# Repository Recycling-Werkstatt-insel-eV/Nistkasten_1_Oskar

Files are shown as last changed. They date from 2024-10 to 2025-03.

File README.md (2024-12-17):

# Vogelnistkasten aus Recycling-Kunststoff und Holz - für Bauworkshops

Dieser Vogelnistkasten wurde so konzipiert, dass einige Teile aus Recycling-Kunststoff (Plastikplatten aus der "Precious-Plastic"-Plattenpresse) und Wände sowie der Boden aus Holzplatten bestehen. Die Holzteile lassen sich mit einem geeigneten Lasercutter ausschneiden oder auch mit einer CNC-Fräse aus Holzbrettern fräsen.

Durch seinen einfachen Aufbau ist dieser Nistkasten sehr gut für Bauworkshops geeignet, sowohl für Grundschulkinder als auch für ältere Jugendliche oder Erwachsene.

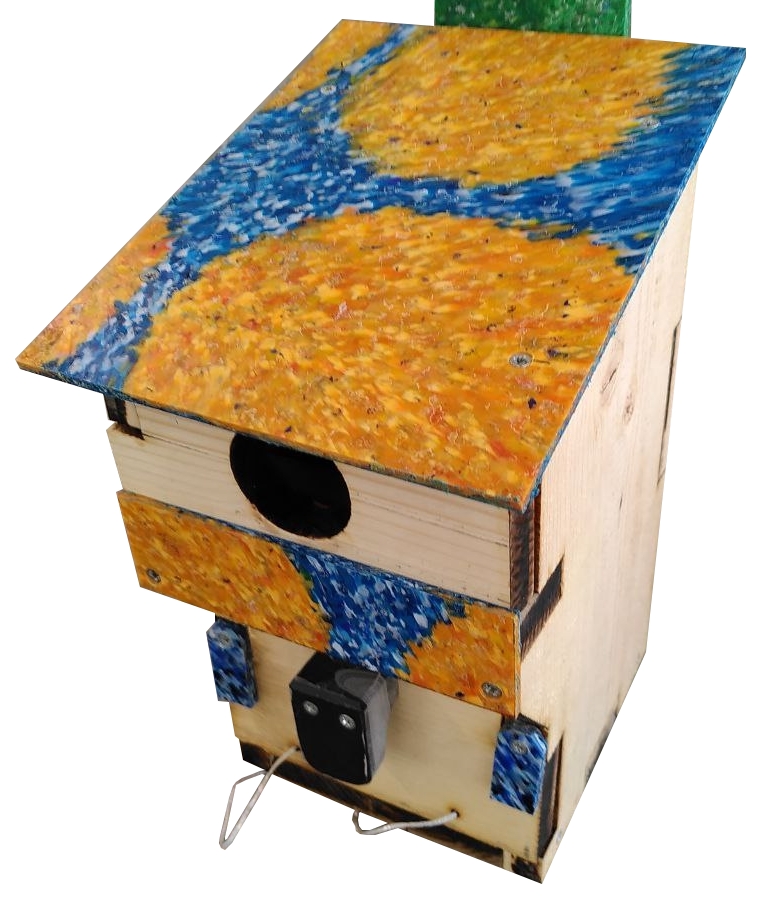
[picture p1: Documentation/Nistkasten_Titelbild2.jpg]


Im Rahmen dieses Projekts wurden noch einige andere Nistkästen entwickelt: [Zur Übersicht](https://github.com/orcular-orga/vogelhaus_uebersicht)

## Bauanleitung

Für einen Nachbau wird empfohlen, die folgenden Kapitel in der vorgesehenen Reihenfolge zu lesen und die Schritte entsprechend abzuarbeiten:

1. 💡 [Hintergrundinfos](Documentation/Hintergrundinfos/Hintergrundinfos.md)
2. 🛒 [Einkaufsliste](Documentation/Einkaufsliste/Einkaufsliste.md)
3. 🪵 [Fertigung der Holzteile (Lasercutting oder CNC-Fräsen)](Documentation/Fertigung_der_Holzteile/Fertigung_der_Holzteile.md)
4. ♻️ [Fertigung der Kunststoffteile](Documentation/Fertigung_der_Kunststoffteile/Fertigung_der_Kunststoffteile.md)
5. 🛠️ [Zusammenbau](Documentation/Documentation.md)
6. 🐣 [Aufhängung der Kästen und Pflege](Documentation/Aufhaengung_Pflege/Aufhaengung_Pflege.md)

## CAD + Open Source

Dieser Nistkasten wurde in der Open-Source-Software FreeCAD entwickelt. Die Datei kann im Ordner CAD heruntergeladen werden:

- [Download der CAD-Datei (FreeCAD)](CAD)

Die Software FreeCAD ist kostenlos und kann auf https://www.freecad.org/ heruntergeladen werden:

- [Download der Software FreeCAD](https://www.freecad.org/)

Alle Bauteile und Objekte in der CAD-Datei des Nistkastens können mit FreeCAD verändert werden, sodass es möglich ist, weitere Varianten zu entwickeln und ggf. öffentlich zu teilen, so wie dieses Projekt - ganz im Sinne von Open Source Hardware.

## Lizenz

Das Design, die CAD-Dateien, die Materiallisten und alle dazugehörigen Dateien dieses Vogelnistkastens sind unter folgender Lizenz veröffentlicht:

- [CERN Open Hardware Licence Version 2 Weakly Reciprocal - CERN-OHL-W](https://cern-ohl.web.cern.ch/)

Die Dokumentation, Bauanleitung, Abbildungen und Texte in diesem Verzeichnis sind unter folgender Lizenz veröffentlicht:

- [Creative-Commons-Attribution-ShareAlike 4.0 International - CC BY-SA 4.0](http://creativecommons.org/licenses/by-sa/4.0/)

**Autor:** Oskar Lidtke, https://github.com/orcular-org/

<br />Except where otherwise noted, this work is licensed under a <a rel="license" href="http://creativecommons.org/licenses/by-sa/4.0/">Creative Commons Attribution-ShareAlike 4.0 International License (CC BY-SA 4.0)</a>.

Für die empfohlene, korrekte Anwendung der Creative-Commons-Namensnennung (engl. "attribution"), siehe [hier](https://wiki.creativecommons.org/wiki/Best_practices_for_attribution) und für die Kennzeichnung der eigenen Arbeit mit Creative Commons, siehe [hier](https://wiki.creativecommons.org/wiki/Marking_your_work_with_a_CC_license).

<p align="left">
<i> <sub> Open Source Hardware logo, <a href="https://creativecommons.org/licenses/by-sa/4.0/">CC BY-SA</a> - <a href="https://www.oshwa.org/open-source-hardware-logo/">Source</a> </sub></i>
</p>



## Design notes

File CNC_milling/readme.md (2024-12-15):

Die beiden Dateien "Nistkasten_20cm_Brettbreite.svg" und "Nistkasten_25cm_Brettbreite.svg" können zum CNC-Fräsen genutzt werden (jeweils für ein Brett 800 x 200 x 18 mm bzw. 800 x 250 x 18 mm). Zum CNC-Fräsen kann je nach CNC-Fräsmaschine eine andere Software verwendet werden, z.B. Estlcam. Anleitung für das CNC-Fräsen [hier](CNC_milling_Documentation/CNC_milling.md).

Download: Eine der SVG-Datei anklicken, dann oben rechts auf die drei Punkte "..." klicken und "Download" wählen. Datei kann bei Bedarf in Vektorgrafikprogrammen geöffnet und bearbeitet werden, z.B. in Inkscape.

Die kostenlose Open-Source-Software Inkscape kann hier heruntergeladen werden: https://inkscape.org/

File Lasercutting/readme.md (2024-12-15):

Die beiden Dateien "Nistkasten_20cm_Brettbreite.svg" und "Nistkasten_25cm_Brettbreite.svg" können zum Lasercutting genutzt werden (jeweils für ein Brett 800 x 200 x 18 mm bzw. 800 x 250 x 18 mm). Zum Lasercutting kann je nach Lasercutter eine andere Software verwendet werden, z.B. Lightburn. Anleitung für das Lasercutting [hier](Lasercutting_Documentation/Lasercutting.md).

Download: Eine der SVG-Datei anklicken, dann oben rechts auf die drei Punkte "..." klicken und "Download" wählen. Datei kann bei Bedarf in Vektorgrafikprogrammen geöffnet und bearbeitet werden, z.B. in Inkscape.

Die kostenlose Open-Source-Software Inkscape kann hier heruntergeladen werden: https://inkscape.org/

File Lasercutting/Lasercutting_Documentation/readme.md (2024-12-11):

Beschreibung des Vorgehens beim Lasercutting

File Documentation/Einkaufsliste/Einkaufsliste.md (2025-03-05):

# Einkaufsliste

Die Mengenangaben in dieser Einkaufsliste beziehen sich auf **einen** Nistkasten. Falls mehrere Nistkästen gebaut werden sollen, können natürlich entsprechend größere Mengen besorgt werden.

**Zum Thema Holz:**

Der NABU empfiehlt zum Thema Holzart folgendes:

_"Verwenden Sie zum Bau von Nistkästen 1,8 Zentimeter dicke, ungehobelte Bretter aus Massivholz. Eiche, Robinie und Lärche oder Kiefer eignen sich am besten. Falls Ihnen diese Holzarten nicht zur Verfügung stehen, können Sie auch auf Fichte und Tanne zurückgreifen. Sperrholz oder Pressplatten sind nicht witterungsbeständig und daher für den Außeneinsatz ungeeignet."_

- Quelle: https://www.nabu.de/tiere-und-pflanzen/voegel/helfen/nistkaesten/index.html , Abschnitt "Das richtige Material"

Für unsere Zwecke haben wir uns für Fichtenholzbretter aus dem Baumarkt entschieden, da sie einen gutes Verhältnis aus Kosten und Eignung bieten. Zudem haben wir in unseren Tests festgestellt, dass sich Fichtenholzbretter gut mit dem Lasercutter schneiden bzw. mit der CNC-Fräse fräsen lassen. Es können aber, entsprechend der oben stehenden Empfehlungen, auch andere Holzarten verwendet werden.

**Zum Thema Recyclingkunststoff:**

Die Offene Recycling-Werkstatt vom insel e.V. Hamburg verfügt über Maschinen, mit denen sich Platten und Balken (sogenannte "Beams") aus Recyclingkunststoff herstellen lassen. Die Maschinen und Verfahren basieren auf dem "Precious Plastic"-Projekt https://www.preciousplastic.com/ (daher stammt auch der englischsprachige Begriff "Beam" - die Platten werden auf englisch "Sheets" genannt).

Die Platten und Balken können, falls die notwendigen Maschinen vorhanden sind, selbst hergestellt werden. Sie können auch bei insel e.V. https://werkstatt.insel-ev.de/ oder auf dem "Precious Plastic Bazar" https://bazar.preciousplastic.com/ bestellt werden. Als Kunststoffsorte kommen sowohl PP als auch HDPE (PE) in Frage.

Für die genauen Maße der Kunststoffteile können auch die technischen Zeichnungen in der Sektion [Fertigung der Kunststoffteile](../../Documentation/Fertigung_der_Kunststoffteile/Fertigung_der_Kunststoffteile.md) eingesehen werden.

**Zum Thema Schrauben:**

Die unten angegebenen Schraubengrößen können auch leicht abweichen, solange sie einerseits einen sicheren Halt bieten und andererseits nicht zu weit aus dem Material herausragen.

## Schrauben

- 6 x Holzschrauben vom Typ 4 x 30 
- 12 x Holzschrauben vom Typ 3,5 x 25
- 2 x Holzschrauben vom Typ 4 x 40

:bulb: Alle Schrauben möglichst mit Senkkopf (Kreuzschlitz oder Torx). Schraubengrößen können auch leicht abweichen. Abbildungen unten nur zur Orientierung, Aussehen der Schrauben kann auch abweichen.

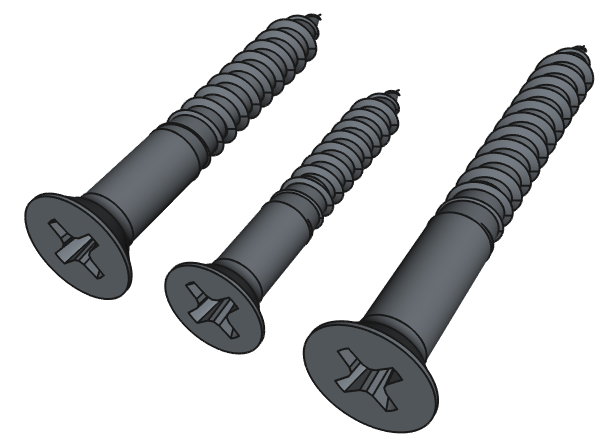
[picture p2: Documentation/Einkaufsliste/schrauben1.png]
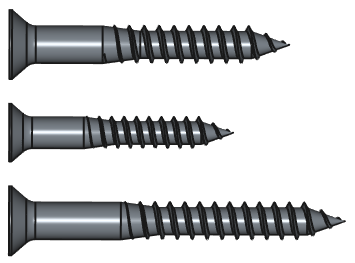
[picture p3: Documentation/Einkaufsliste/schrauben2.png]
 

## Holz

- 1x Brett 800 x 200 x 18 mm aus Fichtenholz
- 1x Brett 800 x 250 x 18 mm aus Fichtenholz

## Kunststoffplatten

- Eine oder mehrere Platten aus Recyclingkunststoff, sodass sich folgende Teile herstellen lassen:
  - 1x Frontplatte 156 x 45 mm (Stärke: 4 bis 5 mm)
  - 3x drehbarer Halter 45 x 18 mm (Stärke 4 bis 5 mm)
  - Dach 220 x 180 mm (Stärke: 5 bis 8 mm)
  - Brett Rückseite 440 x 85 mm (Stärke: 9 bis 10 mm)

Es können also beispielsweise folgende Platten besorgt werden:
- Stärke 4-5 mm, Länge/Breite mindestens 280 x 220 mm 
- Stärke 9-10 mm, Länge/Breite mindestens 440 x 85 mm

## Kunststoffbalken ("Beams")

Ein Stück 48 x 33 x 23 mm, abgeschnitten von einem Kunststoff-Balken ("Beam")

## Aluminiumnägel

Für die Befestigung der Nistkästen an Bäumen sollten pro Nistkasten zwei Alunägel verwendet werden. Mehr zum Thema im Abschnitt 6 "Aufhängung der Kästen und Pflege"

- 2x Alunägel 4,5 x 60 oder 4,5 x 80

Hier geht es [zurück zur Übersicht](../../README.md), dort weiter mit Punkt 3 "Fertigung der Holzteile (Lasercutting oder CNC-Fräsen)".

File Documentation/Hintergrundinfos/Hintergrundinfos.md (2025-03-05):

# Hintergrundinfos

Dieser Vogelnistkasten wurde im Rahmen eines Projekts bei der Offenen-Recycling-Werkstatt (von insel e.V.) in Hamburg https://werkstatt.insel-ev.de/ entwickelt. Die "Deutsche Stiftung für Engagement und Ehrenamt" hat das Projekt gefördert. Projektzeitraum war von November 2023 bis Dezember 2024.

Der Nistkasten ist für verschiedene Höhlenbrüter-Vogelarten geeignet.

Im Rahmen des Projekts sind noch andere Nistkastenmodelle entstanden. Eine Übersicht befindet sich hier: [Übersicht Nistkästen](https://github.com/Recycling-Werkstatt-insel-eV/Nistkasten_main_Uebersicht)

## Besonderheiten des Nistkastens

Ziel der Produktentwicklung war es, einen Nistkasten zu entwickeln, der
1. möglichst aus nachhaltigen Materialien hergestellt werden kann
2. einfach zusammenzubauen ist (auch von Kindern, z.B. im Rahmen von Bauworkshops)
3. mit wenig Aufwand in großer Stückzahl herstellbar ist, d.h. unter Verwendung von digitalen Fertigungsmaschinen wie Lasercutter oder CNC-Fräsen
4. gut dokumentiert ist, damit andere Menschen den Kasten nachbauen oder sogar verbessern oder neue Varianten entwickeln können
5. gut reparierbar und recyclebar ist
6. einen hohen Nutzen für die Vögel und für die Förderung von Artenvielfalt bietet

### Zu Punkt 1: Nachhaltige Materialien

Eine Besonderheit der Offene Recycling-Werkstatt von insel e.V. in Hamburg sind die Werkzeuge und Prozesse zum Recycling von Kunststoffen (Plastik) und Herstellung von neuen Produkten aus Recyclingplastik. Die Werkstatt verfügt u.a. über Granulatmühlen (Schredder) zum Zerkleinern von Kunststoffabfällen sowie über eine Plattenpresse. Das zerkleinerte Plastikgranulat kann in der Plattenpresse zu großen Platten aus Recyclingplastik gepresst werden. Diese Platten können anschließend weiterverarbeitet werden, z.B. mit Tischkreissägen oder Bohrmaschinen. 

Daher bestand ein Ziel darin, die Vogelnistkästen, zumindest teilweise, aus Recyclingkunststoff herzustellen. Während der Konzeptionsphase stellte sich heraus, dass ein Vogelnistkasten nicht vollständig aus Plastik bestehen sollte (dank der Beratung durch die teilnehmenden NABU-Mitglieder_innen). Plastikkästen heizen sich in der Sonne zu stark auf, was den Vögeln schadet, zudem ist Plastik (im Gegensatz zu Holz) nicht atmungsaktiv und es sammelt sich Feuchtigkeit im Innenraum.

Aus diesem Grund wurde ein Modell entwickelt, das teilweise aus Holz und teilweise aus Plastik besteht. Die Wände und der Boden sind aus Holz, sodass sich der Kasten nicht zu stark aufheizt, atmungsaktiv ist und zudem den Jungvögeln gute Klettermöglichkeiten an den Innenflächen bietet. Das Dach und einige weitere Verbindungsteile hingegen wurden aus Recyclingkunststoff gefertigt. Diese haben keine negativen Einflüsse auf das Innenklima. Gleichzeitig sorgt der Einsatz von Recyclingkunststoff dafür, dass wertvolles Holz zumindest teilweise eingespart werden kann. Zudem wird Kunststoffabfällen ein "zweites Leben" gegeben, oder - falls das Plastik erneut recycelt wird - sogar mehrere Leben.

### Zu Punkt 2: Einfacher Zusammenbau

Alle Teile und das gesamte Design wurden so entworfen, dass der Zusammenbau sehr einfach ist. Die Teile sind ähnlich wie ein Puzzle geformt, sodass sie sich einfach und eindeutig zusammenstecken lassen. Dadurch ist auch sichergestellt, dass die Teile richtig sitzen, nicht verrutschen und rechtwinkling zueinander angeordnet sind. Die Stellen, an denen Schrauben befestigt werden müssen, sind durch das Lasercutting bzw. CNC-Fräsen bereits vorgefertigt.

Somit ist der Kasten so konzipiert, dass er im Rahmen von Bauworkshops (ca. 1,5 Stunden) einfach zusammengebaut werden kann, auch von Grundschulkindern. Die Bauworkshops sollten von eingewiesenen Personen angeleitet werden. Die Bauanleitung kann verwendet werden, um Menschen in die Workshopleitung einzuweisen oder für handwerklich erfahrene Personen, die den Nistkasten ohne anleitende Workshopleiter alleine nachbauen möchten.

Der einfache Zusammenbau sorgt nicht zuletzt dafür, dass der Kasten wahrscheinlich recht häufig und in großer Stückzahl nachgebaut werden kann und somit einen möglichst großen Nutzen für den Tierschutz und die Artenvielfalt bringt.

### Zu Punkt 3: Einfache Herstellung in großer Stückzahl / Digitale Fertigung

Ein Produkt, bei dem die Einzelteile nur mit viel Aufwand einzeln von Hand gefertigt werden müssen, hat nur einen geringen Effekt, da es unwahrscheinlicher wird, dass überhaupt viele Produkte entstehen.

Dieser Nistkasten hingegen wurde so konzipiert, dass sich alle wichtigen Teile mithilfe von digitaler Fertigung praktisch "halbautomatisch" herstellen lassen. Alle Holzteile (und prinzipiell auch die Plastikteile) können mit einem Lasercutter oder einer CNC-Fräse mit wenig Zeit- und Personalaufwand hergestellt werden. Dadurch ist es möglich, relativ große Stückzahlen herzustellen. Auch dadurch können mehr Nistkästen entstehen und der Nutzen für Tierschutz und Artenvielfalt wird erhöht.

### Zu Punkt 4: Dokumentation

Der Nistkasten wurde gründlich dokumentiert. Alle wichtigen Infos rund um Materialbeschaffung, Fertigung, Zusammenbau und Verwendung des Nistkastens sind in diesem GitHub-Verzeichnis dokumentiert. Zudem sind alle digitalen Dateien, die zur Fertigung mit Lasercutter oder CNC-Fräse notwendig sind, beigelegt. Auch Zeichnungen und Anweisungen zur Herstellung einzelner Teile sind vorhanden.

Das Projekt ist als Open-Source-Hardware veröffentlicht, sodass jede_r diesen Nistkasten einsehen, nachbauen oder sogar verbessern oder verändern kann.

### Zu Punkt 5: Reparierbarkeit und Recyclebarkeit

Der Nistkasten wurde so designt, dass sich alle Teile wieder einfach voneinander lösen lassen. Es gibt keine Klebverbindungen, nur Steck- und Schraubverbindungen. Damit lässt sich der Nistkasten sehr gut reparieren, da Einzelteile einfach austauschbar sind. Zudem lassen sich alle Einzelteile sortenrein trennen und damit auch recyceln oder anderswo wiederverwenden.

### Zu Punkt 6: Nutzen für Vögel/Artenvielfalt

Dadurch, dass die wesentlichen Teile aus Holz bestehen, bietet der Nistkasten ein gutes Innenklima für (Jung)vögel. Der Kasten ist dank der Schraubverbindungen sehr stabil, auch bei Wind und Wetter. Durch die austauschbaren Lochplatten können verschiedene Vogelarten angesprochen werden. Falls andere Vogelarten unterstützt werden sollen oder falls sich herausstellt, dass die ursprünglich vorgesehe Vogelart gar nicht in der Gegend verkehrt, kann einfach eine Lochplatte mit anderem Lochdurchmesser eingeschoben werden. Es muss also kein neuer Kasten gebaut, sondern nur die Platte ausgetauscht werden, was den Kasten zusätzlich nachhaltig macht.

Zudem verfügt der Nistkasten über einen sogenannten Prädatorenschutz, also Schutz vor Nesträubern. Tiere wie Katzen, Marder oder Waschbären greifen manchmal in Nistkästen hinein und versuchen Eier oder Jungvögel herauszuholen. Der Schutz vor Nesträubern bei diesem Nistkasten besteht in Form der Abstufung im oberen Bereich beim Einflugloch. Das Bauteil "oberer Boden" sorgt dafür, dass die Wand mit dem Einflugloch ein Stück weit vorgezogen ist, sodass die hineingreifenden Nesträuber den unteren Bereich des Nistkastens, wo das Nest liegt, nicht erreichen können.

## Vogelarten und Einfluglochgrößen

Je nachdem, von welcher Vogelart der Nistkasten genutzt werden soll, kann eine andere Lochscheibe verwendet werden.

Zum einen kann man sich daran orientieren, welche Vogelart in der Gegend besonders gefährdet ist und unterstützt werden soll. Andererseits kann es aber auch sinnvoll sein, zu beobachten, welche Vögel überhaupt in der Gegend verkehren, sodass der Nistkasten für diese Vögel angepasst wird.

Falls man sich unsicher ist und sowieso mehrere Nistkästen aufhängt, kann man verschiedene Lochgrößen ausprobieren (jeden Nistkasten mit einem anderen Loch) und beobachten, welche Kästen gut angenommen werden und die anderen Kästen entsprechend mit der gleichen Lochplatte ausstatten.

Übliche empfohlene Lochgrößen je nach Vogelart sind in der folgenden Tabelle zu sehen:

| Art | Optimales Einflugloch (Durchmesser) |
| --- | --- |
| Blaumeise | 26-28 mm  |
| Tannenmeise  | 26-28 mm  |
| Haubenmeise  | 26-28 mm  |
| Sumpfmeise  | 26-28 mm  |
| Weidenmeise  | 26-28 mm  |
| Kohlmeise  | 32 mm  |
| Kleiber  | 32 - 45 mm  |
| Trauerschnäpper  | 32 - 34 mm  |
| Haussperling (Spatz)  | 32 - 34 mm  |
| Feldsperling (Spatz) | 32 mm |
| Star | 45 mm  |
| Gartenrotschwanz | oval: 48 mm hoch, 32 mm breit  |

Quelle: NABU - https://www.nabu.de/tiere-und-pflanzen/voegel/helfen/nistkaesten/01083.html

Für diesen Nistkasten wurden drei verschiedene Lochgrößen entworfen: 27 mm, 32 mm und 45 mm. Damit lassen sich fast alle Vogelarten in der oben stehenden Tabelle abdecken.

Ein Vorschlag für einige ausgewählte Vogelarten ist in folgendem Bild zu sehen:

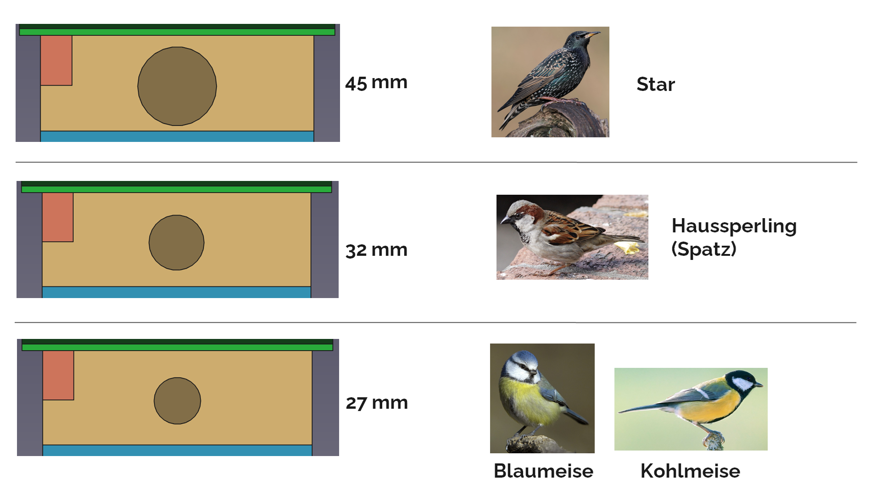
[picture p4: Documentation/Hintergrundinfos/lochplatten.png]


Für den ersten Zusammenbau im Bauworkshop kann zunächst eine beliebige Lochplatte verwendet werden. Die anderen beiden Lochplatten kann man ebenfalls herstellen und mitnehmen, um sie später je nach Bedarf austauschen zu können.

Hier geht es [zurück zur Übersicht](../../README.md), dort weiter mit Punkt 2 "Einkaufsliste".

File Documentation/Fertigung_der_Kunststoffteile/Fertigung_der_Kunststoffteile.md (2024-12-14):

# Fertigung der Kunststoffteile

Die Kunststoffteile können z.B. mit Tischkreissägen und Bohrmaschinen hergestellt werden. Dieses Dokument enthält alle wichtigen Infos dazu. Die Zeichnungen können als PDF-Datei heruntergeladen können (Link ganz unten).

Das Lasercutting von Kunststoffplatten haben wir getestet, es führte jedoch nicht zu guten Ergebnissen und zu starker Rauchbildung. Es wird davon abgeraten, Kunststoffteile mit dem Lasercutter zu schneiden. Stattdessen sollten Kunststoffplatten entweder mit Kreissägen, Bohrmaschinen etc. hergestellt werden (so haben wir es auch gemacht). CNC-Fräsen wäre prinzipiell auch möglich. Die entsprechenden Vektorgrafiken können aus der [FreeCAD-Datei](../../CAD) heraus mittels der Funktion [Shape2DView](https://wiki.freecad.org/Draft_Shape2DView) erstellt werden.

## Benötigte Materialien

Die Materialien für die Herstellung der Kunststoffteile können in der [Einkaufsliste](../../Documentation/Einkaufsliste/Einkaufsliste.md), Abschnitte "Kunststoffplatten" und "Kunststoffbalken ("Beams")", eingesehen werden.

## Benötigte Werkzeuge

- Tischkreissäge oder Formatkreissäge oder anderes Werkzeug, das zum Sägen der Kunststoffplatten geeignet ist
- Bohrmaschine (empfohlen wird eine Standbohrmaschine, aber Handbohrmaschine funktioniert auch)
- Bohrer in den Durchmessern 3 mm, 4 mm und 4,5 mm (einfache Metallbohrer reichen aus)
- Senkkopfbohrer mit entsprechenden Durchmessern
- Feile

## Zeichnungen

Die Teile sollten entsprechend der unten verlinkten Zeichnungen hergestellt werden. Von den "Drehbaren Haltern Plastik" sollten zwei Stück hergestellt werden (oder drei Stück, falls die Lochplatte gesichert werden soll, siehe letzten Schritt in der [Bauanleitung](../../Documentation/Documentation.md)). Von allen anderen Teilen reicht je ein Stück pro Nistkasten.

Download der Zeichnungen (PDF-Datei):

- [Zeichnungen Kunststoffteile](Zeichnungen_Kunststoffteile.pdf)

Die PDF-Datei kann direkt in GitHub eingesehen oder heruntergeladen werden (über die drei Punkte oben rechts "..." > Download). Die Datei ist in A4-Format und kann somit auch gut ausgedruckt werden (5 Seiten).

Hier geht es [zurück zur Übersicht](../../README.md), dort weiter mit Punkt 5 "Zusammenbau".

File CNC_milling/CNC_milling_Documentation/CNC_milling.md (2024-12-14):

# CNC-Fräsen

Mit einer CNC-Fräse haben wir sehr gute und saubere Ergebnisse erzielt. Die CNC-Fräse sollte möglichst groß genug sein, um die 80 x 25 cm großen Bretter bearbeiten zu können, sodass alle Teile pro Brett in einem Durchgang gefräst werden können. Bei kleineren CNC-Maschinen müssten die Teile ggf. einzeln aus kleineren Brettern gefräst werden.

Wir haben eine CNC-Fräsmaschine vom Typ "WorkBee Z1+" von der Firma Ooznest verwendet, was sehr gut funktioniert hat.

Der Fräser sollte mindestens 18-22 mm lang sein, um die 18 mm dicken Bretter komplett durchfräsen zu können. Wir haben folgenden Fräser benutzt und damit sehr gute Erfahrungen gemacht: VHM Holzfräser, d=4, L=22 (C), Z=2, Blank

In Folgenden wird beispielhaft eine Möglichkeit für CNC-Fräsen beschrieben.

## Fräswerkzeug

Fräsdurchmesser = 4 mm, Länge mind. 20 mm, z.B.  VHM Holzfräser, d=4, L=22 (C), Z=2, Blank

## SVG-Dateien

Die 2D-SVG-Vektorgrafiken können [hier](../) heruntergeladen werden. Bei Bedarf können die Grafiken mit der kostenlosen Software Inkscape https://inkscape.org/ angepasst werden (z.B. Teile anders anordnen). 

## Software

Wir haben mit der Software Estlcam https://www.estlcam.de/ gute Erfahrungen gemacht. Mit dieser Software ist es relativ einfach möglich, 2D-SVG-Vektorgrafiken einzufügen und alle notwendigen Einstellungen und Fräsvorgänge einzurichten.

Es können auch andere Programme verwendet werden, auch 3D-basierte CAM-Programme. Hierfür kann in CAD-Datei (in [diesem Ordner](../../CAD)) in FreeCAD geöffnet und die Teile in FreeCAD oder einem anderen Programm für das CNC-Fräsen vorbereitet werden.  

## Fräs-Parameter

Wir haben in Estlcam unter "Werkzeugliste" folgenden Fräsen hinzugefügt:

- Name: Fräser 4 mm
- Durchmesser: 4 mm
- Tiefenzustellung je Durchgang: 2 mm
- Eintauchwinkel: 90 °
- Vorschubgeschwindigkeit: 1400 mm/min
- Eintauchgeschwindigkeit: 700 mm/min
- Drehzahl: 22000 upm

Die Drehzahleinstellung war in unserem Fall nicht relevant, weil bei der verwendeten CNC-Fräsmaschine der Fräser als separates Gerät in der Halterung sitzt und die Drehzahl nicht über die CAM-Software, sondern direkt am Fräser eingestellt wird.
Wir haben eine mittlere Drehzahl eingestellt. Da jede Fräsmaschine, jeder Fräser und jedes Holz anders ist, wird empfohlen, zunächst einige kleine, vorsichtige Test-Fräsungen durchzuführen und zu erproben, welche Drehzahl am besten funktioniert. Auch die anderen, oben stehenden Parameter können so erprobt und noch angepasst werden.

## Befestigung der Bretter

Die Bretter mit vier Schrauben an der Opferplatte der Fräsmaschine befestigen. Die Schrauben möglichst weit in der Ecke platzieren und nochmals nachmessen, ob für die geplanten Fräsauftrag eine Kollision mit den Schrauben ausgeschlossen werden kann. Ansonsten ggf. ein Bauteil aus der Datei entfernen und die Teile so verschieben, dass sie genug Abstand zu den Schrauben haben.

## Schmales Brett (20 cm Breite)

Für das schmale Brett mit 20 cm Breite (800 x 200 x 18 mm) wird folgende Anordnung empfohlen:

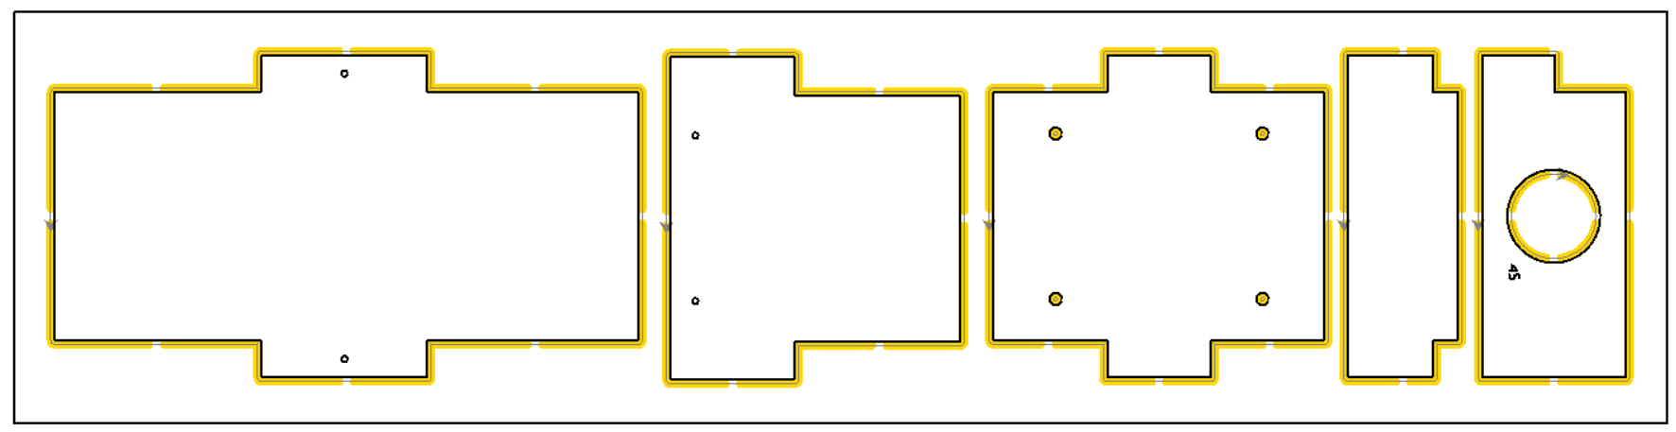
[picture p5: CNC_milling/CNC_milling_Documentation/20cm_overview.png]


Die SVG-Datei kann [hier](../) heruntergeladen werden.

## Breites Brett (25 cm Breite)

Für das schmale Brett mit 20 cm Breite (800 x 250 x 18 mm) wird folgende Anordnung empfohlen:

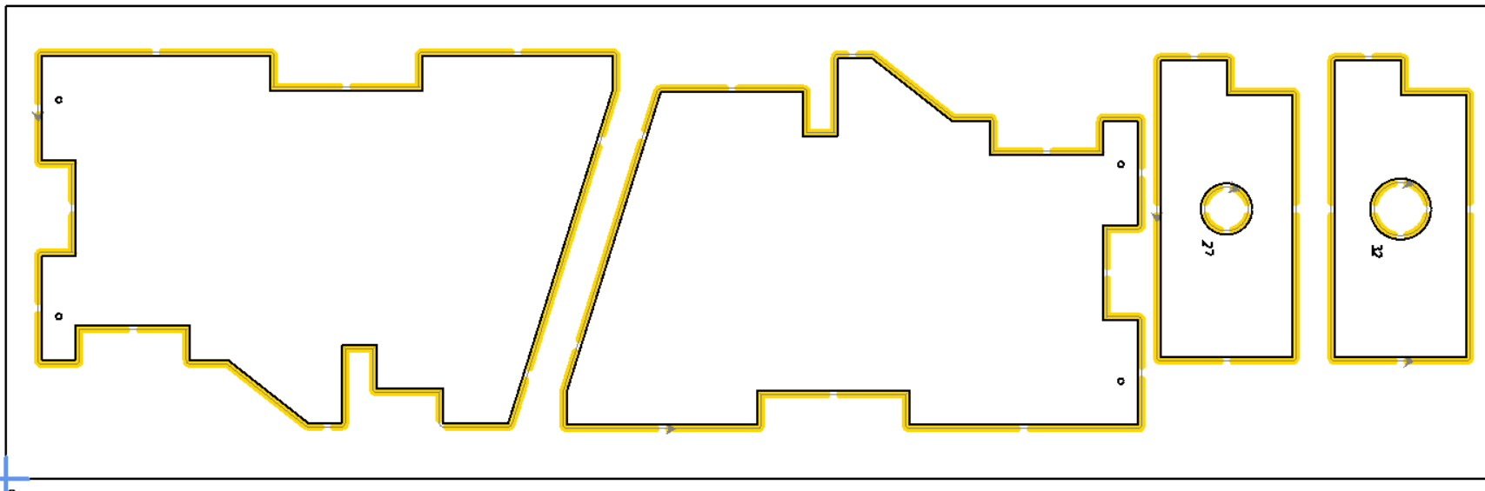
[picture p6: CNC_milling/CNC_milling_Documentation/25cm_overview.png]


Die SVG-Datei kann [hier](../) heruntergeladen werden.

## Fräsbahnen definieren

Zunächst müssen die Fräsbahnen definiert werden (siehe gelb markierte Bahnen in den Abbildungen oben). In Estlcam kann die Funktion "Teil" genutzt werden, um die Außenbahnen der Teile festzulegen. Für die Innenbahnen (Einflugloch in der Lochplatte sowie die vier Wasserablauflöcher im Boden) wird die Funktion "Ausschnitt" verwendet.

## Anbindung der Teile

Alle Teile sollten mit Stegen angebunden werden. In den Abbildungen oben sind die gelben Fräsbahnen an einigen Stellen unterbrochen. Es wird empfohlen, die Anbindestege an diesen Stellen zu platzieren. Eine andere Anordnung ist jedoch auch möglich, solange sichergestellt ist, dass die Teile beim ausfräsen einen sicheren Halt haben.

In Estlcam kann hierfür eine Fräsbahn ausgewählt und anschließend die Funktion "Anbinden" genutzt werden.

Hier noch ein Detailbild von der inneren Fräsbahn beim Einflugloch mit den vier Unterbrechungen (Stellen für die Anbindestege):

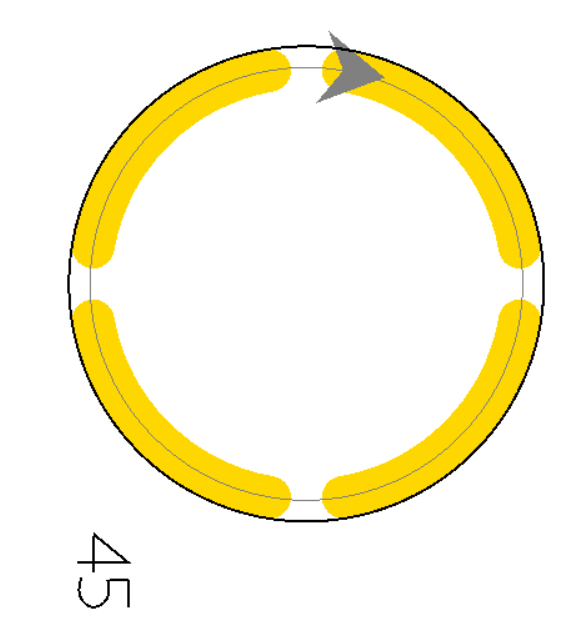
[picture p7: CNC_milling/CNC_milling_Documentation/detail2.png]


Die Zahl "45" (siehe oberes Bild) zeigt den Lochdurchmesser zur Orientierung an. Die Zahl sollte nicht gefräst werden (oder mit einem sehr kleinen Fräser "eingraviert" werden). Die Zahl kann nach dem Fräsen von Hand draufgeschrieben oder mit einem Lasercutter eingraviert werden.

## Ecken freifräsen

Damit die Teile später gut zusammenpassen, wir empfohlen, alle innenliegenden Ecken freizufräsen. Hintergrund ist, dass der Fräsen wegen seines runden Querschnitts innenliegende Ecken nicht ganz freifräsen kann, sondern immer eine Rundung mit dem Durchmesser des Fräsers übrig bleibt.

In Estlcam kann hierfür eine Fräsbahn ausgewählt und anschließend die Funktion "Freifräsen" genutzt werden.

Die folgenden zwei Abbildungen zeigen ein Beispiel für freigefräste Ecken. Im ersten Bild links sind die Ecken noch nicht freigefräst, im zweiten Bild rechts wurde "Freifräsen" korrekt hinzugefügt:

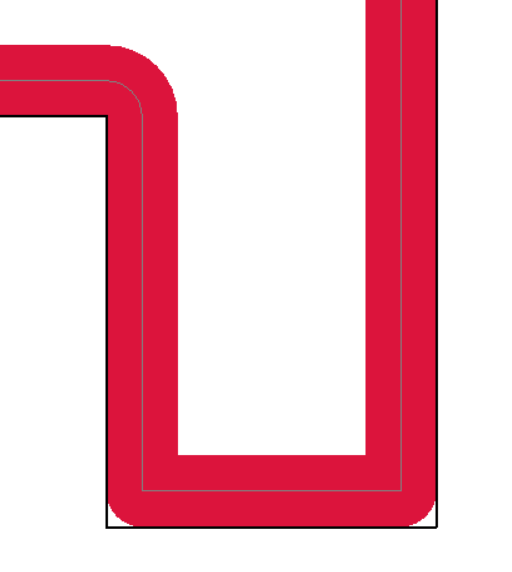
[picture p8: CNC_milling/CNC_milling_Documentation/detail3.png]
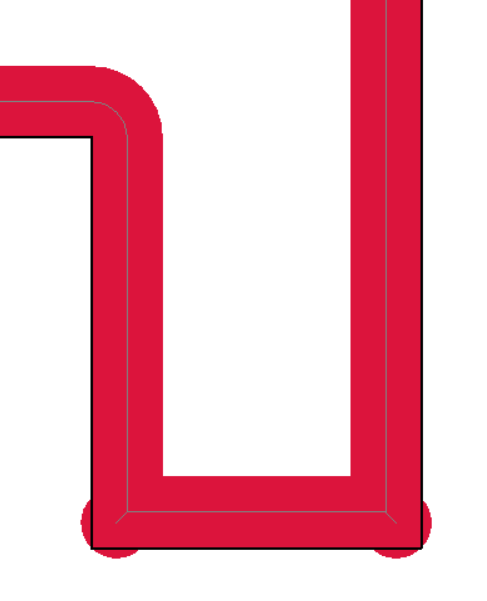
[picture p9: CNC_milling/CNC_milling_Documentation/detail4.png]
 

## Prüfung und CNC-Programm-Export

Abschließend sollte jede Fräsbahn nochmals ausgewählt und kontrolliert werden, ob die Parameter und der Fräser richtig eingestellt sind. Danach kann die Datei als über Datei > CNC-Programm speichern exportiert werden. Als Bauteilhöhe sollte die Brettdicke (18 mm) oder etwas mehr eingestellt werden.

## Nachbearbeitung

An den fertig gefrästen Teilen können die Haltestege vorsichtig mit einem stabilen Cuttermesser durchgeschnitten werden. Es können auch kleine Handsägen, Stichsägen oder andere Werkzeuge verwendet werden. Ggf. übrige Reste abschleifen oder feilen.

Die folgenden Abbildungen zeigen den Fräsvorgang sowie die Haltestege:

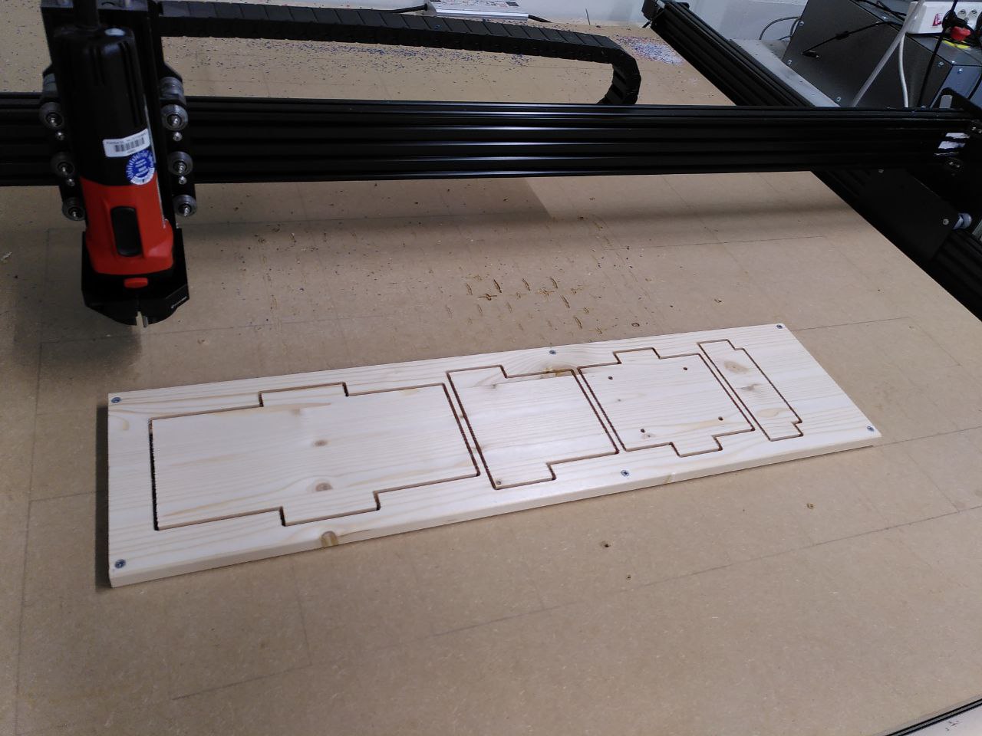
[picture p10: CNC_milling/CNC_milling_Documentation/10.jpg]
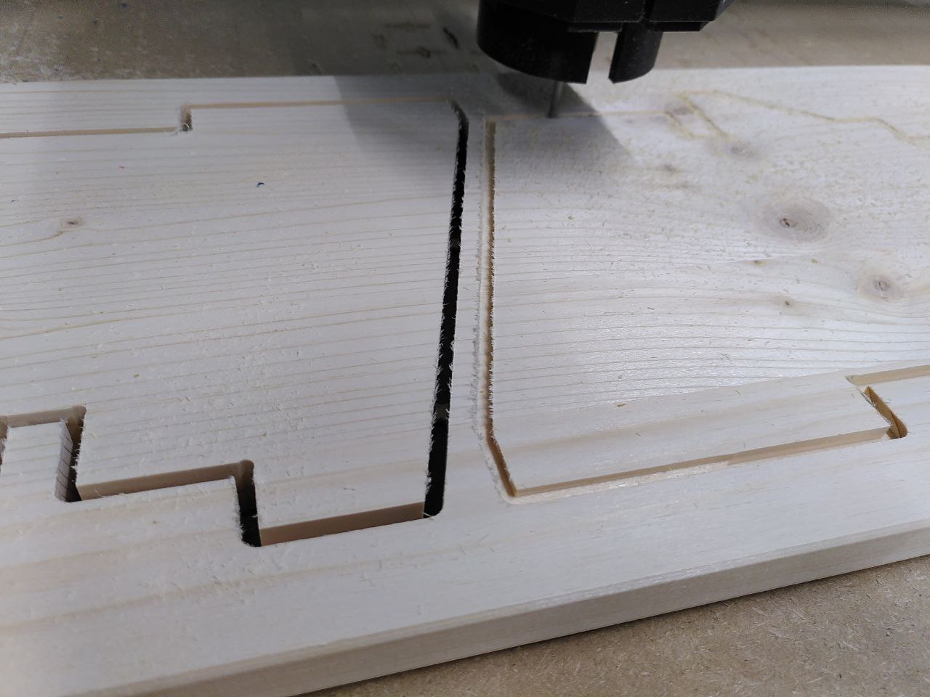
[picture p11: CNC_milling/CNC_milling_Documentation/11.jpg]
 

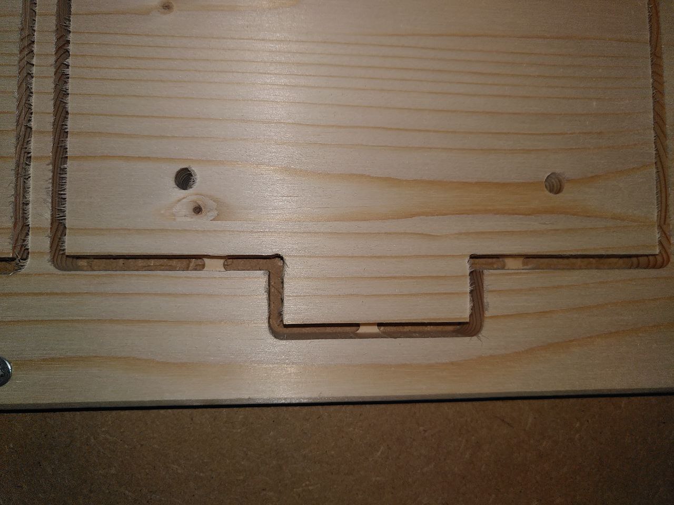
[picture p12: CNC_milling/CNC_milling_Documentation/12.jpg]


Hier geht es [zurück zur Übersicht](../../README.md), dort weiter mit Punkt 4 "Fertigung der Kunststoffteile".

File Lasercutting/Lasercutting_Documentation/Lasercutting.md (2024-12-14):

# Lasercutting

Es ist möglich, die Holzteile für den Vogelnistkasten mit einem Lasercutter zu schneiden. Allerdings sind nicht alle Lasercutter dafür geeignet.

Zunächst sollte sichergestellt werden, dass der Lasercutter in der Lage ist, 18 mm dicke Holzbretter aus Fichtenholz zu schneiden. Hierfür muss die Bedienungsanleitung des Lasercutter geprüft oder beim Hersteller des Lasercutter nachgefragt werden. In diesem Projekt wurde ein CO2-Lasercutter mit 130 W Laserleistung eingesetzt. Bei Lasercuttern mit weniger Leistung muss genau geprüft bzw. getestet werden, ob die Holzbretter durchgeschnitten werden können.

In unserem Fall haben wir ein Lasercutter-Modell Omtech Max 1493 / USB1410b (130 Watt) benutzt. Die Fertigung war erfolgreich, wenn auch mit ein paar Komplikationen verbunden, z.B. gingen manche Schnitte nicht ganz durch, sodass mit einer Stichsäge nachgesägt werden musste. Zudem waren die Kanten/Ränder relativ stark verbrannt und schwarz, sodass wir viel mit Tellerschleifer und Schleifpapier nacharbeiten mussten. Auch die Rauchentwicklung beim Lasercutting war recht stark, eine gute Abluftanlage wird auf jeden Fall benötigt.

Daher wird eher das CNC-Fräsen empfohlen (Beschreibung siehe [hier](../../Documentation/Fertigung_der_Holzteile/Fertigung_der_Holzteile.md)), das deutlich weniger Probleme macht. Es kann auch sein, dass andere Lasercutter oder andere Einstellungen zu besseren Ergebnissen führen - daher gerne ausprobieren und bei Erfolg freuen wir uns über eine Rückmeldung.

Im Folgenden wird beispielhaft eine Möglichkeit des Lasercuttings der Teile beschrieben. Die Teile wurden auf zwei Bretter Fichtenholz (800 x 200 x 18 mm und 800 x 250 x 18 mm) verteilt. Das Lasercutter-Modell war ein Omtech Max 1493 / USB1410b (130 Watt) unter Verwendung der Software "Lightburn".

## Sicherheit

Es wird dringend empfohlen, vor Inbetriebnahe eines Lasercutters gängige Sicherheitsempfehlungen für Lasercutter zu beachten, z.B. einen CO2-Feuerlöscher sowie eine Löschdecke bereitzuhalten und sich mit der Anwendung vertraut zu machen. Sollte sich während des Laserschneidens eine unkontrollierte Flamme über das Holzbrett ausbreiten, sollte der Laserjob gestoppt werden. Falls die Flammen nicht kurzfristig von alleine erlöschen, sollten sie mit einer Löschdecke oder mit einem CO2-Feuerlöscher gelöscht werden.

Das Lasercutten von 18 mm dicken Holzbrettern ist grundsätzlich möglich, allerdings relativ anspruchsvoll. Nach unseren Tests liegen 18 mm Brettstärke nahe der Grenze dessen, was mit Lasercutting von Holz möglich ist. Während des Laserschneidens ist damit zu rechnen, dass Flammen entstehen (vor allem bei harzhaltigem Holz wie Fichte). Ein "Air Assist"-System sowie eine gute Abluft- und Filteranlage mit hohem Volumenstrom sind dringend zu empfehlen, damit die Flamme unter Kontrolle bleibt bzw. kurzfristig ausgeblasen werden kann und damit die entstehenden Rauchgase zuverlässig abgeführt werden können.

Das Schneiden von Kunststoffplatten haben wir getestet, es führte jedoch nicht zu guten Ergebnissen und zu starker Rauchbildung. Es wird davon abgeraten, Kunststoffteile mit dem Lasercutter zu schneiden. Stattdessen sollten Kunststoffplatten entweder mit Kreissägen oder mit der CNC-Fräse bearbeitet werden - mehr dazu im Dokument "Fertigung der Kunststoffteile".

## SVG-Dateien

Die 2D-SVG-Vektorgrafiken können [hier](../) heruntergeladen werden. Bei Bedarf können die Grafiken mit der kostenlosen Software Inkscape https://inkscape.org/ angepasst werden (z.B. Teile anders anordnen). Bei der Verwendung der Software "Lightburn" können die Teile auch dort bearbeitet werden.

## Laser-Parameter

Bei dem o.g. Modell (Omtech Max 1493 / USB1410b (130 Watt)) werden folgende Einstellungen empfohlen:

- Schneiden:
  - Leistung: 35 %
  - Geschwindigkeit: 6 mm/s
  - Anzahl der Schnittdurchläufe: 2
- Gravieren:
  - Leistung: 15 %
  - Geschwindigkeit: 50 mm/s
 
Die Anzahl der Schnittdurchläufe ist hier mit zwei (2) angegeben. Dies kann z.B. in Lightburn über den Parameter "Anzahl der Durchläufe" gesteuert werden. Es wird allerdings empfohlen, den Parameter auf 1 zu setzen und dafür den Laserjob zwei mal hintereinander durchlaufen zu lassen. Andernfalls werden alle Linien direkt hintereinander zwei mal geschnitten, was die Gefahr von Flammbildung erhöht.
 
In den [herunterladbaren SVG-Dateien](../) sind Schnittlinien schwarz und Gravuren rot angelegt. In der Software Lightburn können die Parameter entsprechend angepasst werden. Der grüne Rand in den Abbildungen unten stellt das Brett dar und sollte nicht gelasert werden.

Die roten (gravierten) Zahlen stehen für den Lochdurchmesser in Millimeter. Für einen Nistkästen können alle drei Lochplatten angefertigt werden, damit sie später ausgetauscht werden können, oder es wird nur die Lochplatte gefertigt, die benötigt wird. Mehr zu dem Thema im Kapitel "Hintergrundinfos".
 
## Schmales Brett (20 cm Breite)

Für das schmale Brett mit 20 cm Breite (800 x 200 x 18 mm) wird folgende Anordnung empfohlen:

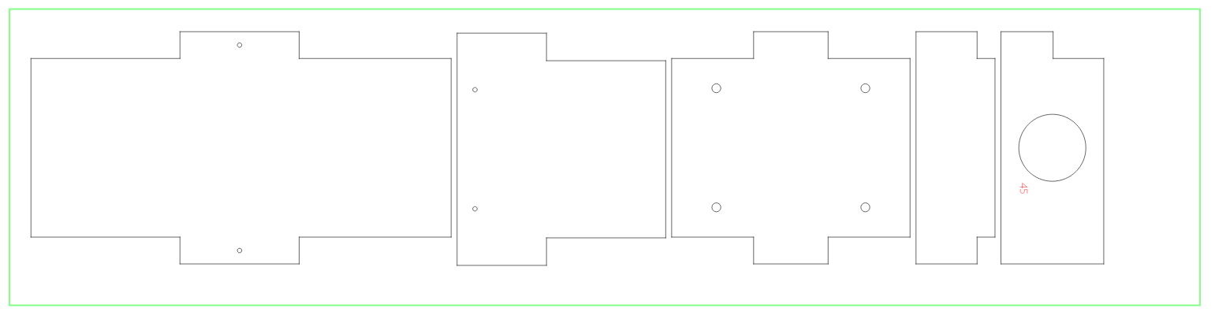
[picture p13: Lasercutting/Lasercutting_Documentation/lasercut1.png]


- Schwarz = Schnittlinien
- Rot = Gravur
- Grün = Brettrand (nicht lasern)

Die SVG-Datei kann [hier](../) heruntergeladen werden.

## Breites Brett (25 cm Breite)

Für das breite Brett mit 25 cm Breite (800 x 250 x 18 mm) wird folgende Anordnung empfohlen:

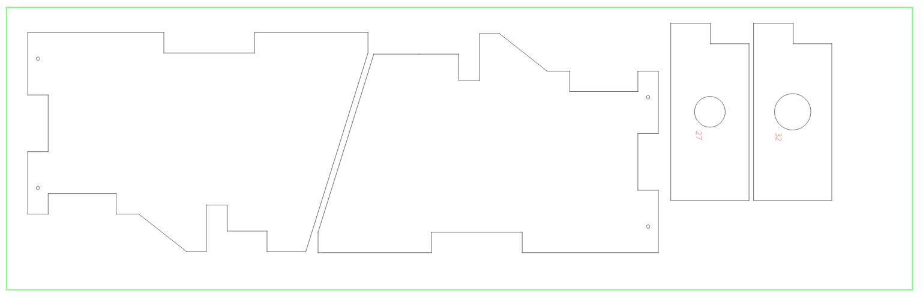
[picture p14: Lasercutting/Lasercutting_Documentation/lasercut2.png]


Die SVG-Datei kann hier [hier](../) heruntergeladen werden.

## Nachbearbeitung

Nach unserer Erfahrung kommt es gelegentlich vor, dass Teile noch im Holzbrett feststecken, da Schnittlinien teilweise nicht ganz durchgingen. In dem Fall ist es ggf. notwendig, die Teile z.B. mit einer Stichsäge nachzusägen.

Die Ränder der Teile sind durch das Lasercutting oft stark verbrannt und schwarz. Es wird empfohlen, die Randpartien der Teile abzuschleifen, z.B. an einem Tellerschleifer und/oder mit Schleifpapier.

Hier geht es [zurück zur Übersicht](../../README.md), dort weiter mit Punkt 4 "Fertigung der Kunststoffteile".

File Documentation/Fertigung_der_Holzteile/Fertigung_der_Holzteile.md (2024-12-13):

# Fertigung der Holzteile

Es gibt zwei Möglichkeiten, die Holzteile für den Nistkasten mit digitalen Fertigungsmaschinen herzustellen: entweder mit einem Lasercutter oder mit einer CNC-Fräse. Je nachdem, welche Maschine man zur Verfügung hat, kann man eine der Optionen wählen. Falls beide Maschinen vorhanden sind, kann dieses Dokument eine Entscheidungshilfe bieten, um zu prüfen, was mehr Sinn macht. Grundsätzlich wird eher das CNC-Fräsen empfohlen (zur Begründung siehe unten).

Hier geht es zu den jeweiligen Anleitungen:
- [Lasercutting](../../Lasercutting/Lasercutting_Documentation/Lasercutting.md)
- [CNC-Fräsen](../../CNC_milling/CNC_milling_Documentation/CNC_milling.md)

Prinzipiell lassen sich die Holzteile natürlich auch von Hand, also z.B. mit Kreis- und Stichsägen herstellen. Die Teile sind jedoch recht komplex geformt, sodass es viel Aufwand wäre. Damit die Teile gut passen, kommt es auch sehr auf Präzision an. Es macht also auf jeden Fall Sinn, Lasercutting oder CNC-Fräsen zu nutzen - hierfür wurden die Teile auch eigentlich konzipiert.

## Lasercutting

Es ist möglich, die Holzteile für den Vogelnistkasten mit einem Lasercutter zu schneiden. Allerdings sind nicht alle Lasercutter dafür geeignet.

Zunächst sollte sichergestellt werden, dass der Lasercutter in der Lage ist, 18 mm dicke Holzbretter aus Fichtenholz zu schneiden. Hierfür muss die Bedienungsanleitung des Lasercutter geprüft oder beim Hersteller des Lasercutter nachgefragt werden. In diesem Projekt wurde ein CO2-Lasercutter mit 130 W Laserleistung eingesetzt. Bei Lasercuttern mit weniger Leistung muss genau geprüft bzw. getestet werden, ob die Holzbretter durchgeschnitten werden können.

In unserem Fall haben wir ein Lasercutter-Modell Omtech Max 1493 / USB1410b (130 Watt) benutzt. Die Fertigung war erfolgreich, wenn auch mit ein paar Komplikationen verbunden, z.B. gingen manche Schnitte nicht ganz durch, sodass mit einer Stichsäge nachgesägt werden musste. Zudem waren die Kanten/Ränder relativ stark verbrannt und schwarz, sodass wir viel mit Tellerschleifer und Schleifpapier nacharbeiten mussten. Auch die Rauchentwicklung beim Lasercutting war recht stark, eine gute Abluftanlage wird auf jeden Fall benötigt.

Daher wird eher das CNC-Fräsen empfohlen, das deutlich weniger Probleme macht. Es kann auch sein, dass andere Lasercutter oder andere Einstellungen zu besseren Ergebnissen führen - daher gerne ausprobieren und bei Erfolg freuen wir uns über eine Rückmeldung.

In dem oben [verlinkten Dokument](../../Lasercutting/Lasercutting_Documentation/Lasercutting.md) wird beispielhaft eine Möglichkeit des Lasercuttings beschrieben.

## CNC-Fräsen

Mit einer CNC-Fräse haben wir sehr gute und saubere Ergebnisse erzielt. Die CNC-Fräse sollte möglichst groß genug sein, um die 80 x 25 cm großen Bretter bearbeiten zu können, sodass alle Teile pro Brett in einem Durchgang gefräst werden können. Bei kleineren CNC-Maschinen müssten die Teile ggf. einzeln aus kleineren Brettern gefräst werden.

Wir haben eine CNC-Fräsmaschine vom Typ "WorkBee Z1+" von der Firma Ooznest verwendet, was sehr gut funktioniert hat.

Der Fräser sollte mindestens 18-22 mm lang sein, um die 18 mm dicken Bretter komplett durchfräsen zu können.
Wir haben folgenden Fräser benutzt und damit sehr gute Erfahrungen gemacht: VHM Holzfräser, d=4, L=22 (C), Z=2, Blank

In dem oben [verlinkten Dokument](../../CNC_milling/CNC_milling_Documentation/CNC_milling.md) wird beispielhaft eine Möglichkeit für CNC-Fräsen beschrieben.

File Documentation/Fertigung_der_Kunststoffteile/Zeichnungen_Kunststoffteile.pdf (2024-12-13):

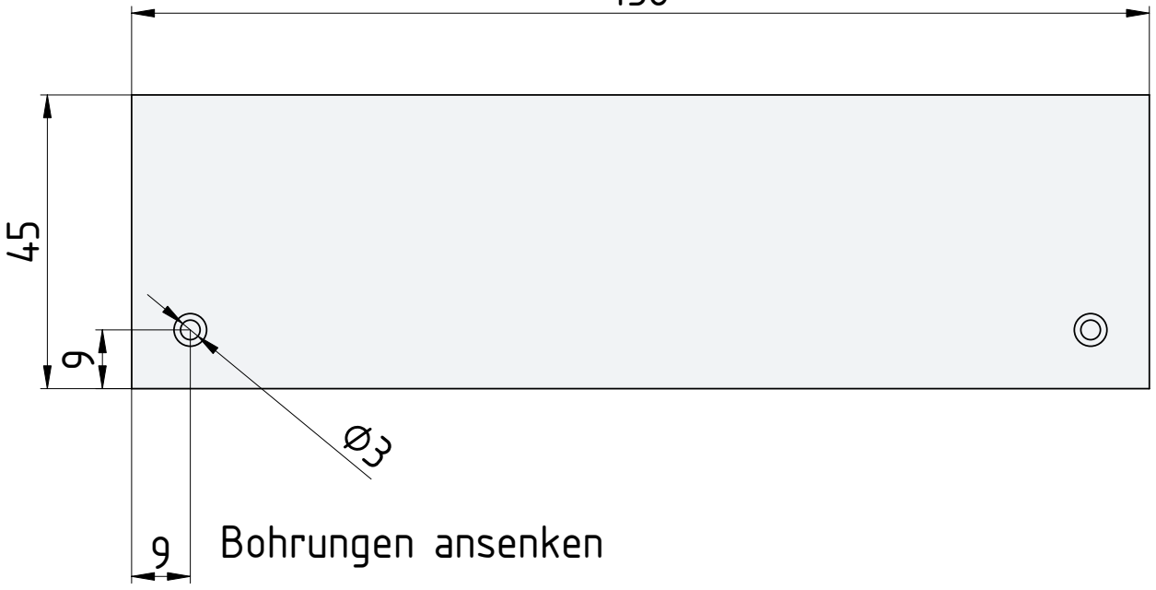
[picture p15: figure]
Bohrungen ansenken

156

4

### Plattendicke

ca. 4 bis 5 mm

### Frontplatte Plastik

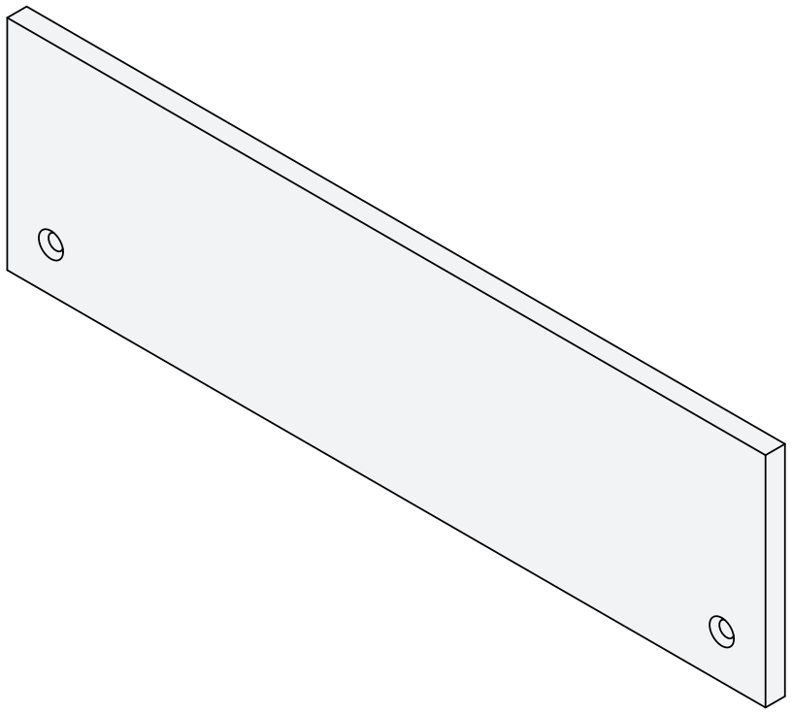
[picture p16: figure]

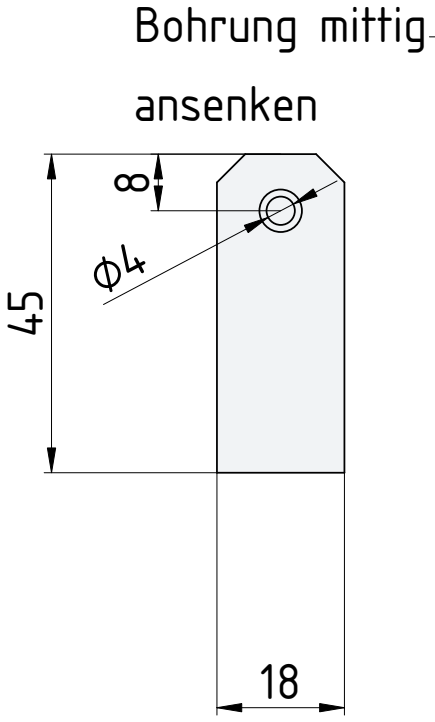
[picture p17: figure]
Bohrung mittig; ansenken

4

### Plattendicke

ca. 4 bis 5 mm

### Drehbarer Halter Plastik

### Griff Plastik

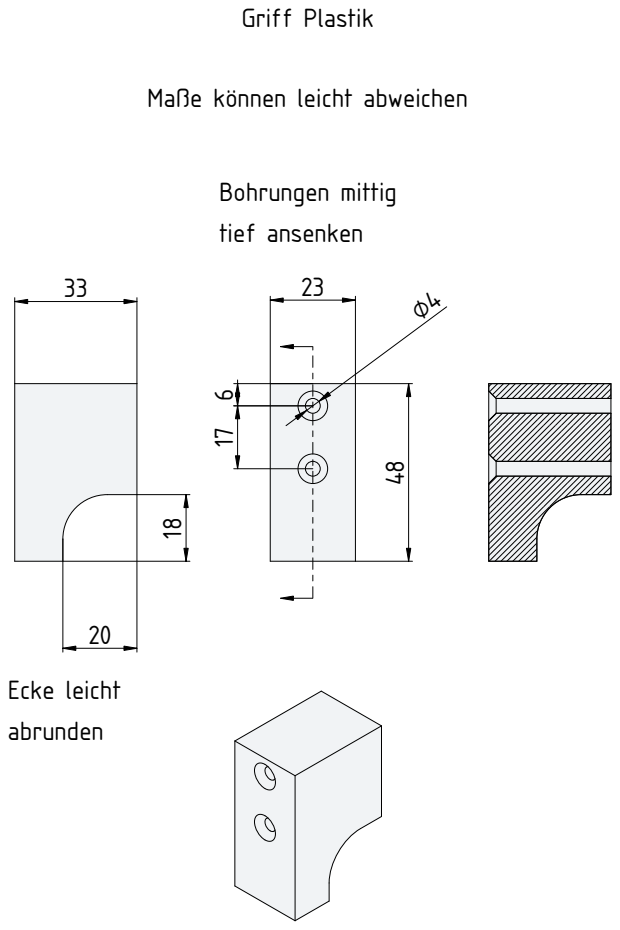
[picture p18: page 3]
Bohrungen mittig; tief ansenken; Ecke leicht; abrunden

Maße können leicht abweichen

180

5

### Dach Plastik

### Plattendicke

ca. 5 bis 8 mm

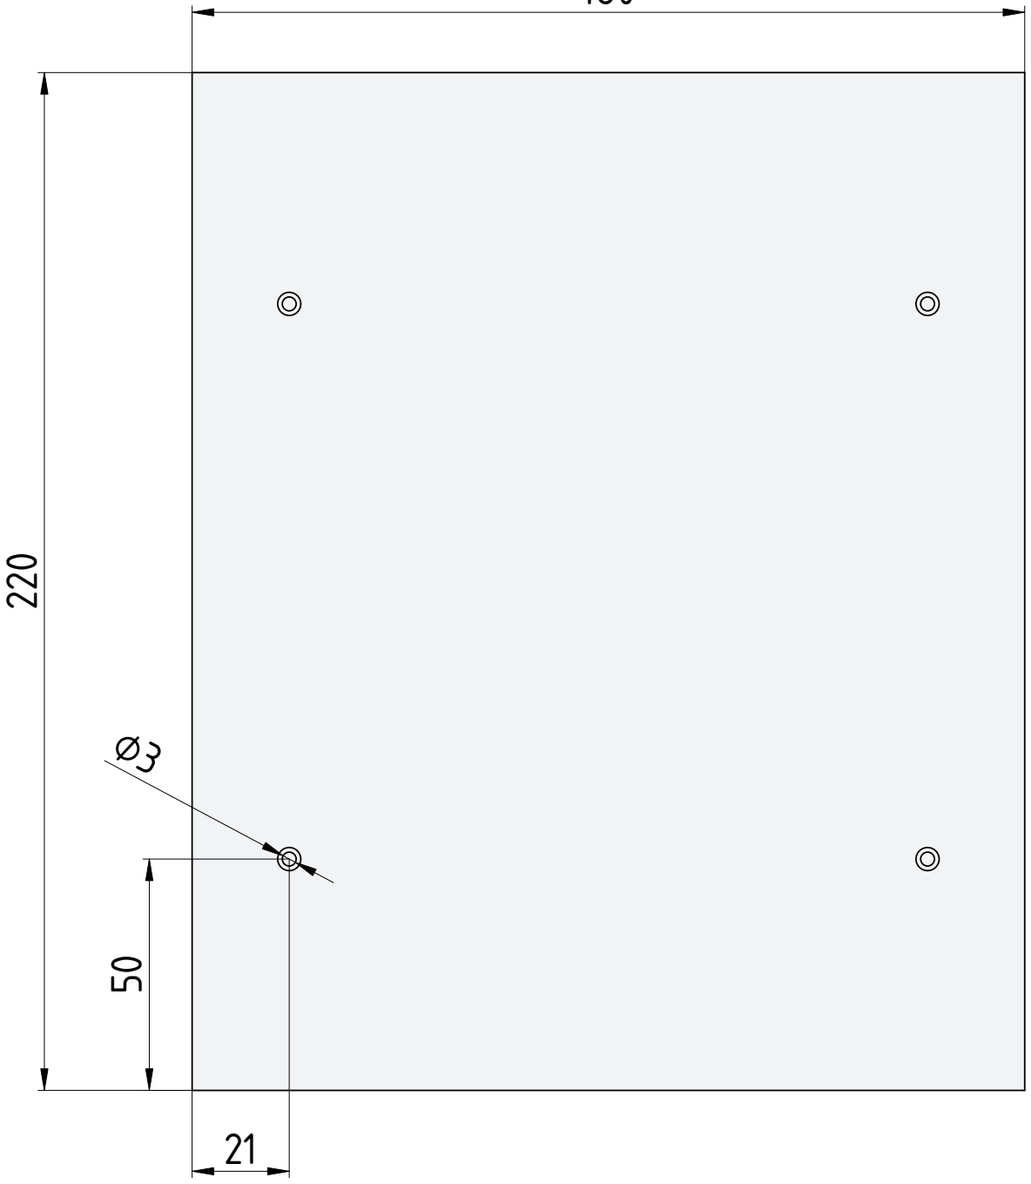
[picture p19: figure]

4 Bohrungen symmetrisch angeordnet

ansenken

85
10
Brett Rückseite Plastik | Plattendicke
| ca. 9 bis 10 mm

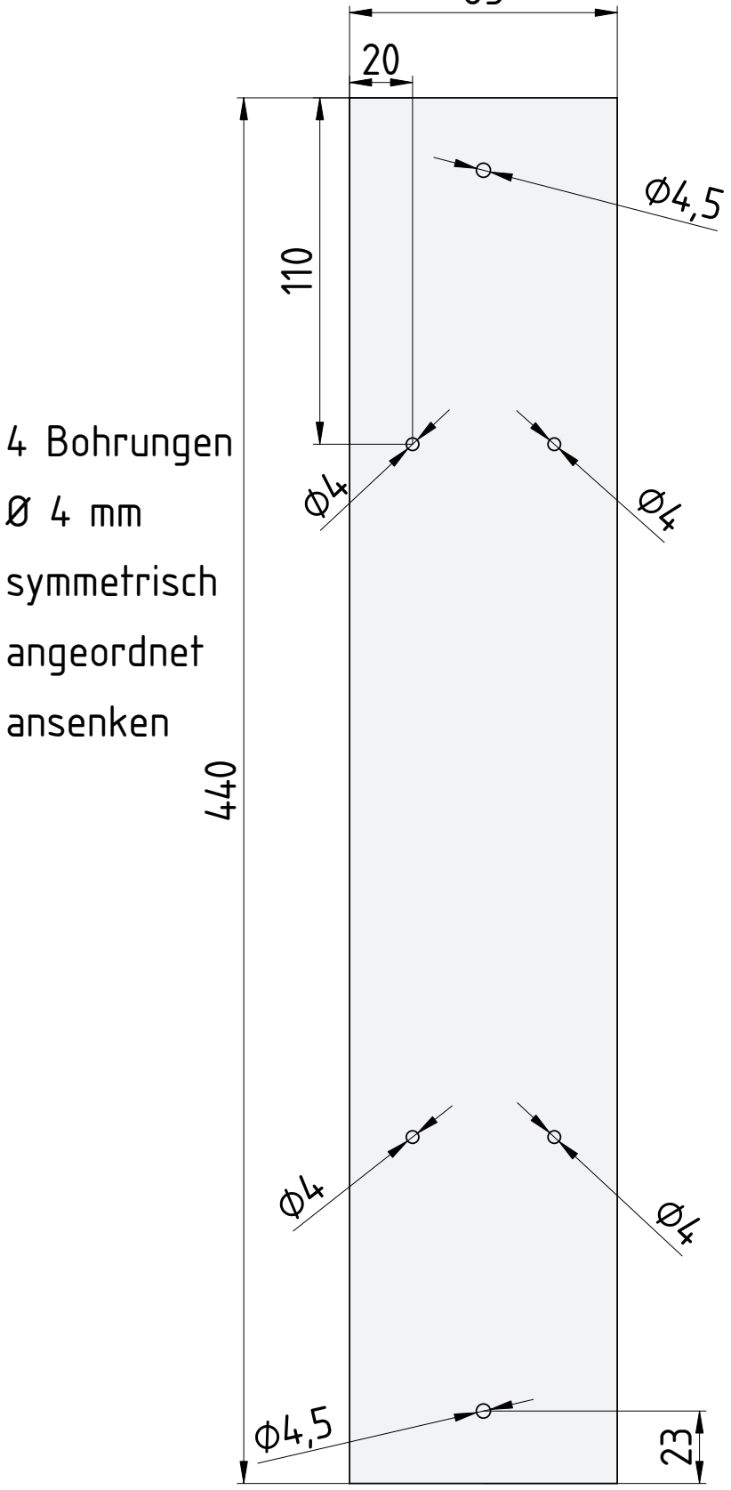
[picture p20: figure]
4 Bohrungen; symmetrisch; angeordnet; ansenken

2 Bohrungen Ø 4,5 symmetrisch angeordnet

(für die Alunägel / Baumbefestigung)

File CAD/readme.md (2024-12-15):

Die Datei "Vogelnistkasten.FCStd" wurde in FreeCAD erstellt. Download: Datei anklicken, dann oben rechts auf die drei Punkte "..." klicken und "Download" wählen. Datei kann dann in FreeCAD geöffnet und bearbeitet werden.

Die kostenlose Open-Source-Software FreeCAD kann hier heruntergeladen werden: https://www.freecad.org/

Hinweis zum Thema Schrauben im FreeCAD-Modell: Da in der "Fasteners"-Workbench von FreeCAD keine Holzschrauben nach DIN verfügbar sind, wurden Holzschrauben nach US-amerikanischer Norm (ASME) eingefügt. Die Größen entsprechen nahezu den eigentlich einzusetzenden Schrauben (siehe [Einkaufsliste](../Documentation/Einkaufsliste/Einkaufsliste.md) und [Zusammenbau](../Documentation/Documentation.md)).

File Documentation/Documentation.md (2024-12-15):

# Zusammenbau

## Bauteile anfertigen

Bevor der Nistkasten nach dieser Anleitung zusammengebaut wird, sollten alle Holz- und Kunststoff-Teile angefertigt werden.

Falls du das noch nicht gemacht hast, gehe [zurück zur Übersicht](../README.md) und bearbeite die Punkte: "Fertigung der Holzteile", "Fertigung der Kunststoffteile" und besorge vorher die Teile von der "Einkaufsliste".

## Material- und Werkzeugliste

### Material/Bauteile

Schrauben:
- 6 x Holzschrauben vom Typ 4 x 30 
- 12 x Holzschrauben vom Typ 3,5 x 25
- 2 x Holzschrauben vom Typ 4 x 40

:bulb: Alle Schrauben möglichst mit Senkkopf (Kreuzschlitz oder Torx). Schraubengrößen können auch leicht abweichen. Abbildungen unten nur zur Orientierung, Aussehen der Schrauben kann auch abweichen.

 

Lasergeschnittene bzw. CNC-gefräste Holzteile:
- 7x Holzteile (lasergeschnitten oder CNC-gefräst), davon eine Lochplatte mit Einflugloch
- 2x weitere Lochplatten mit unterschiedlichen Lochdurchmessern

Zugesägte Teile aus Recycling-Kunststoff:

- 1x Frontplatte aus Recycling-Kunststoff
- 2x Halter aus Recycling-Kunststoff (oder drei Stück, falls die Lochplatte locker sitzt und gesichert werden muss)
- 1x Dach aus Recyclingkunststoff
- 1x Plastikbrett für die Rückseite (Baumbefestigung) aus Recyclingkunststoff

Sonstiges:
- 2x Schnur (jeweils ca. 15-20 cm lang) (Optional, geht auch ohne - zur Sicherung der Frontklappe/Tür)

### Werkzeuge

- Akkuschrauber
- Passende Bits für Kreuzschlitz- und/oder Torx-Schrauben (je nach verwendeter Schrauben)
- Bohrer 3 mm Durchmesser
- Schraubendreher (Kreuzschlitz und/oder Torx) (Optional, falls kein Akkuschrauber zur Verfügung steht oder falls Schrauben von Hand angezogen werden sollen)
- 1-2 Schraubzwingen (optional, vereinfacht die Montage)
- Feile (falls Teile nicht passen und nachbearbeitet werden müssen)
- Raspel (zum Anrauen der Innenfläche der Frontplatte/Tür)
- Standbohrmaschine (falls sich herausstellt, dass noch irgendwo Bohrungen fehlen - eigentlich anzufertigen im Abschnitt "Fertigung der Holzteile" bzw. "Fertigung der Kunststoffteile")

## Bauanleitung

Vorbereitung:

- Überprüfe, ob alle Teile vorhanden sind (vergleiche Bild unten - nicht alle Teile sind in dem Bild zu sehen, aber die Teile im Bild werden zuerst benötigt)
- Die linke Wand und rechte Wand sehen etwas unterschiedlich aus - Stelle sicher, dass du sie richtig anordnest
- Überprüfe, ob die vier Löcher in der Bodenplatte frei sind. Diese sind sehr wichtig, damit Regenwasser innerhalb des Nistkastens ablaufen kann. Falls einzelne Löcher nicht frei sind, bohre sie etwas auf (am besten mit einem 6 mm Bohrer und Akkuschrauber oder Standbohrmaschine)

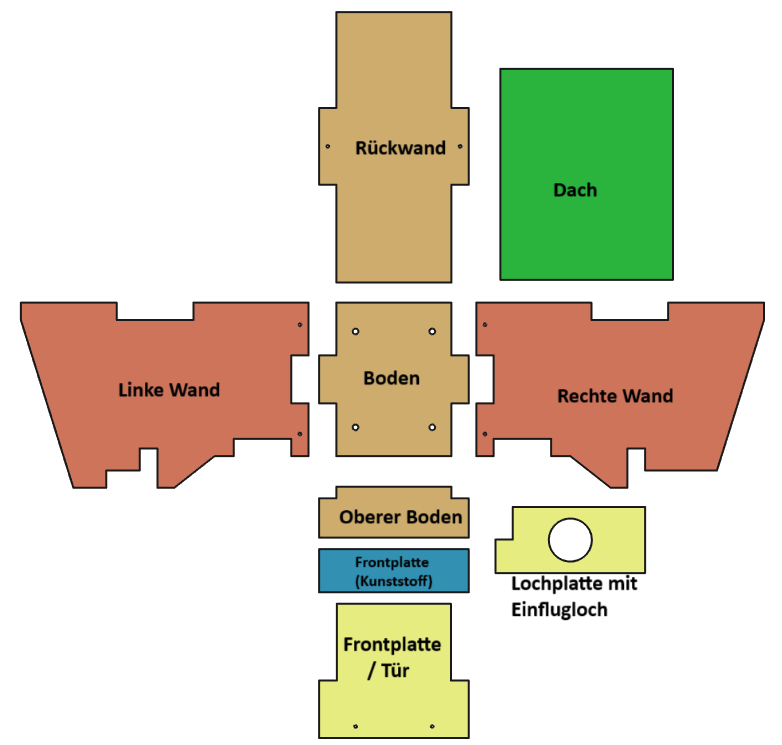
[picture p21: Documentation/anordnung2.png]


- Stecke alle Holzteile zusammen (zunächst ohne Schrauben, nur lose zusammenstecken) und prüfe, ob alle Teile gut zusammenpassen (folge der bebilderten Anleitung unten)
- Falls einzelne Teile nicht passen sollten, bearbeite die entsprechenden Ecken und Kanten nach (z.B. mit einer Feile)
- Wenn alles gut zusammenpasst, zerlege die Teile wieder

Anrauen der Frontplatte/Tür:

- Die Frontplatte/Tür muss von einer Seite angeraut werden, damit die Jungvögel daran hochklettern können (wichtig!)
  - Entscheide, welche Seite der Frontplatte/Tür auf die Innenseite soll
  - Raue die Fläche mit der Raspel gründlich an
  - Zusätzlich kannst du einen breiten Schraubendreher benutzen, um einige Rillen in die Fläche zu schlagen

Zusammenbau:

- Beginne nun mit den Teilen Boden, linke Wand, Rückwand und rechte Wand und stecke sie in dieser Reihenfolge zusammen
- Du kannst 1-2 Schraubzwingen benutzen, um die Teile vorläufig zusammenzuhalten
- Verwende 6 Holzschrauben vom Typ 4 x 30, um die Teile an den vorgesehenen Bohrungen miteinander zu verbinden (nutze einen Akkuschrauber oder einen Schraubendreher)
- An den beiden Seitenteilen (links/rechts) sind ganz unten jeweils zwei Bohrungen; An der Rückwand sind auf mitterer Höhe zwei Bohrungen (siehe Bilder unten)

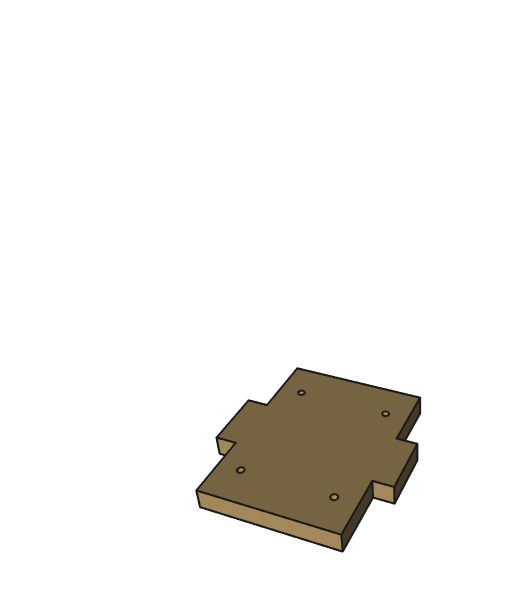
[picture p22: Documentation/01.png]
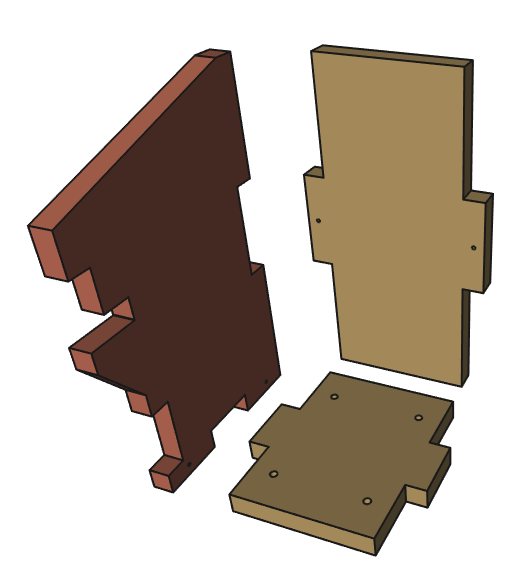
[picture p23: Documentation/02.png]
 

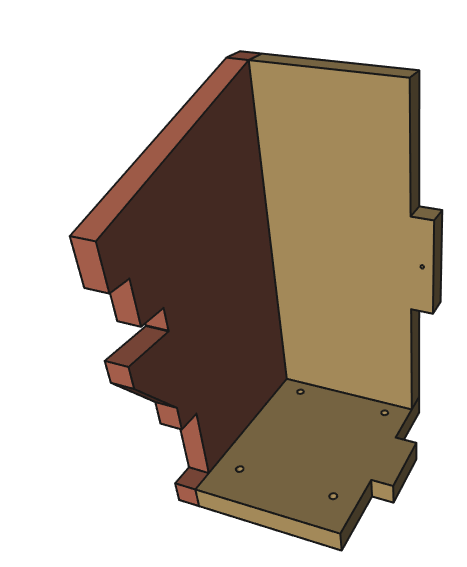
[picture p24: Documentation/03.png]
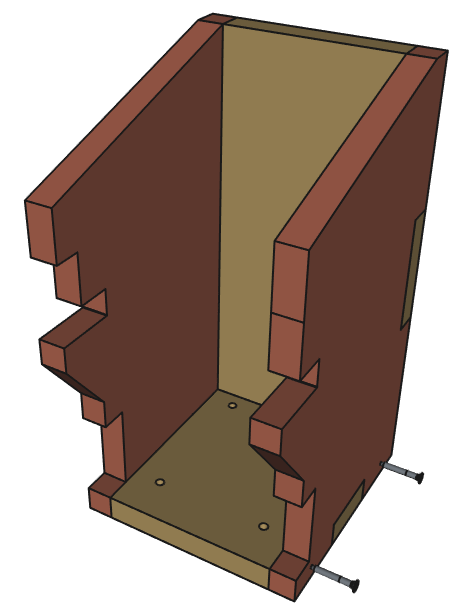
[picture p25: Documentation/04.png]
 



- Setze das Teil "Oberer Boden" in die Lücke ein (siehe Bild unten) und stelle sicher, dass es hineinpasst. Falls nicht, feile etwas nach.

 

- Bohre an den markierten Stellen (Bild unten) zwei Bohrungen
  - Verwende einen Akkuschrauber mit 3 mm Bohrer
  - Die Bohrungen einfach mittig auf der Fläche platzieren oder verwende die Frontplatte aus Recyclingkunststoff als Schablone zum Anzeichnen
  - Es reicht, wenn die Löcher ungefähr so tief sind wie die Schraubenlänge (ca. 2,5 cm) 



- Befestige die Frontplatte aus Recyclingkunststoff (im Bild blau) am Nistkasten. Verwende dafür zwei Holzschrauben 3,5 x 25 und die beiden vorgebohrten Löcher
- Nimm eine Lochplatte mit Einflugloch und schiebe sie seitlich in die Halterung
  - Falls die Platte nicht hineinpasst, lockere die beiden Schrauben an der Frontplatte ein wenig
  - Falls die Platte sehr leicht reingeht und keinen festen Sitz hat, kannst du die Schrauben etwas fester anziehen
  - Stelle sicher, dass die Lochplatte gut einschiebbar ist, aber trotzdem einen möglichst festen Sitz hat und nicht hinausrutscht
 
  :bulb: Falls es nicht möglicht ist, den Sitz der Lochplatte fest zu bekommen und sie leicht herausrutscht, kannst du auch eine zusätzliche Drehhalterung montieren - mehr dazu ganz am Ende der Anleitung. 

  

Frontplatte / Tür + Griff:

- Platziere den Griff mittig auf der Frontplatte/Tür
  - Achte darauf, dass du den Griff auf der glatten Seite platzierst und nicht auf der angerauten Seite. Die angeraute Seite soll auf der Innenseite des Nistkastens liegen
- Befestige den Griff mit zwei Schrauben 4 x 40. Wenn nötig, versenke die Schrauben etwas tiefer, sodass sie genug Halt im Holz haben
- Achte darauf, dass die Schrauben nicht zu tief sitzen - sie sollen **nicht** auf der anderen Seite hinausgucken, weil sich die Vögel sonst daran verletzen könnten

 

 - Setze die Tür in den Nistkasten ein
- Bohre an den markierten Stellen (Bild unten) zwei Bohrungen
  - Verwende einen Akkuschrauber mit 3 mm Bohrer
  - Die Bohrungen einfach mittig auf der Fläche platzieren oder verwende die beiden drehbaren Halter aus Recyclingkunststoff als Schablone zum Anzeichnen
  - Es reicht, wenn die Löcher ungefähr so tief sind wie die Schraubenlänge (ca. 2,5 cm)
 
 

- Verwende 2 Holzschrauben vom Typ 3,5 x 25, um die beiden drehbaren Halter zu befestigen
- Wichtig: Stelle sicher, dass du die drehbaren Halter so platzierst, dass sie
  - im geschlossenen Zustand die Tür festhalten
  - im geöffneten Zustand die Tür nicht blockieren
- Falls sich die drehbaren Halter nicht gut drehen lassen bzw. blockieren, feile die Ecken etwas mit einer Feile nach 

 

Dach:

- Platziere das Dach mittig auf die Oberseite des Nistkastens
- Achte darauf, dass das Dach hinten nicht übersteht, weil da später noch das Plastikbrett für die rückseitige Befestigung dran muss (siehe Bild unten, grüner Rahmen und grüner Pfeil)
- Verwende 4x Holzschrauben vom Typ 3,5 x 25 zum Befestigen des Dachs

  

Plastikbrett Rückseite:

- Platziere das Plastikbrett mittig auf der Rückseite des Nistkastens
- Verwende 4x Holzschrauben vom Typ 3,5 x 25 zum Befestigen des Plastikbretts

 

:bulb: Das Brett dient als Baumbefestigung. Die beiden Löcher ganz oben und unten im Plastikbrett bleiben vorerst frei. Bei der Befestigung am Baum werden Alunägel durch die Löcher geschlagen. 

Schnüre (optional):

- Die Frontplatte/Tür kann zusätzlich mit zwei ca. 15-20 cm langen Schnüren gesichert werden
- Vorteil: Sobald der Nistkasten hoch im Baum hängt und die Tür geöffnet wird (zur Reinigung), kann sie nicht hinunterfallen bzw. muss man die Tür nicht die ganze Zeit in der Hand halten, sondern kann sie an den Schnüren hängen lassen
- Die Schnüre einfach durch die Löcher in der Tür und im Boden führen (gelbe Linien im Bild unten) und festknoten



Zusätzliche drehbare Halterung (nur, falls notwendig):

- Falls eine der Lochplatten nicht gut hält und leicht herausrutscht, kann sie durch einen zusätzlichen drehbaren Halter gesichert werden (siehe Bild)



Der Nistkasten ist nun bereit zum Aufhängen. Hier geht es [zurück zur Übersicht](../README.md), dort weiter mit Punkt 6 "Aufhängung der Kästen und Pflege".

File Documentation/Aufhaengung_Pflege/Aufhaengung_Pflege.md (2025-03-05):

# Aufhängung der Kästen und Pflege

Beim Aufhängen und bei der Pflege der Nistkästen gibt es einige Sachen zu beachten.

## Lochgröße

Für diesen Nistkasten stehen Lochplatten mit den Lochdurchmessern 27 mm, 32 mm und 45 mm zur Verfügung. Damit lassen sich fast alle Vogelarten aus der Tabelle im Dokument "Hintergrundinfos" abdecken. Mehr Infos zu den Vogelarten und zur Auswahl der richtigen Lochgröße im Dokument [Hintergrundinfos](../../Documentation/Hintergrundinfos/Hintergrundinfos.md), Abschnitt "Vogelarten und Einfluglochgrößen".

## Aufhängung

- Die Nistkästen sollten in zwei bis drei Meter Höhe aufgehängt werden.
- Bäume eigenen sich gut zum Anbringen der Nistkästen, aber auch andere Orte wie Hauswände oder hohe Zäune sind möglich. Das Rückseitige Plastikbrett ist für die Anbringung am Baum konzipiert, kann aber bei Bedarf auch weggelassen oder durch eine andere Konstruktion ersetzt werden.
- Bei der Anbringung am Baum kann das rückseitige Plastikbrett genutzt werden. Durch die beiden Löcher oben und unten sollten Alu-Nägel (z.B. 4,5 x 60 oder 4,5 x 80) genutzt werden. Stahlnägel sollten vermieden werden, da sie dem Baum schaden können und sollte der Baum irgendwann gefällt und zersägt werden, können Stahlnägel die Kettensägen beschädigen, während Alu-Nägel kein Problem darstellen.
- Nistkästen für Vögel sollten im Halbschatten und wenn möglich nicht nach Westen oder zur Wetterseite hin angebracht werden. Unter einem Dachvorsprung ist die Himmelsrichtung dagegen egal, nur sehr sonnige Südfassaden sollten gemieden werden
- Damit kein Regen eindringen kann, sollte ein Nistkasten niemals nach hinten, eher nach vorne überhängen.
- Nisthilfen gleicher Bau- und Zielvogelart sollten in Abständen von mindestens zehn Metern aufgehängt werden (Ausnahme: Koloniebrüter wie Sperlinge, Stare und Schwalben). So ist gewährleistet, dass die brütenden Tiere auch genügend Nahrung für sich und ihren Nachwuchs finden. Bei Nisthilfen für verschiedene Arten sollte ein Abstand von mindestens drei Metern zwischen den Nisthilfen eingehalten werden.
- Die beste Zeit zum Aufhängen ist im Herbst an, damit Vögel, Kleinsäuger und Insekten sie zum Schlafen und Überwintern nutzen können.

Quelle (mit einigen Überarbeitungen übernommen): https://www.nabu.de/tiere-und-pflanzen/voegel/helfen/nistkaesten/index.html , Abschnitt "Nistkästen richtig anbringen" 

## Reinigung und Pflege

- Nistkästen sollten nach der Brutsaison gereinigt werden, um neuen Platz zu schaffen und die Belastung durch Flöhe, Milben oder Lausfliegen zu reduzieren. Die Reinigung sollte im Spätsommer oder erst wieder Ende Februar vorgenommen werden. Wenn dann nicht ausgeschlossen werden kann, dass zum Beispiel Siebenschläfer oder andere Tiere noch im Nistkasten überwintern oder Vögel bereits mit der neuen Brutsaison begonnen haben, sollte man die Reinigung besser für ein Jahr bis zum nächsten Spätsommer aussetzen.
- Es sollten Handschuhe getragen werden und das Nistmaterial sollte man nicht in die Wohnung tragen, da Vogelflöhe und anderes Getier auf den Menschen überspringen können.
- Es genügt, das alte Nest zu entfernen und den Kasten bei stärkerer Verschmutzung auszubürsten. Auf Insektensprays oder chemische Reinigungsmittel sollte verzichtet werden.
- Kontrollen während der Brutzeit sollte man vermeiden, um die Brut und Aufzucht der Jungvögel nicht zu stören.
- [Mehr zum Thema Nistkastenreinigung](https://www.nabu.de/tiere-und-pflanzen/voegel/helfen/nistkaesten/02716.html)

Quelle (mit einigen Überarbeitungen übernommen): https://www.nabu.de/tiere-und-pflanzen/voegel/helfen/nistkaesten/index.html , Abschnitt "Nistkästen reinigen" 

An dieser Stelle endet die Anleitung und Dokumentation zum Nistkasten. Hier geht es [zurück zur Übersicht](../../README.md).

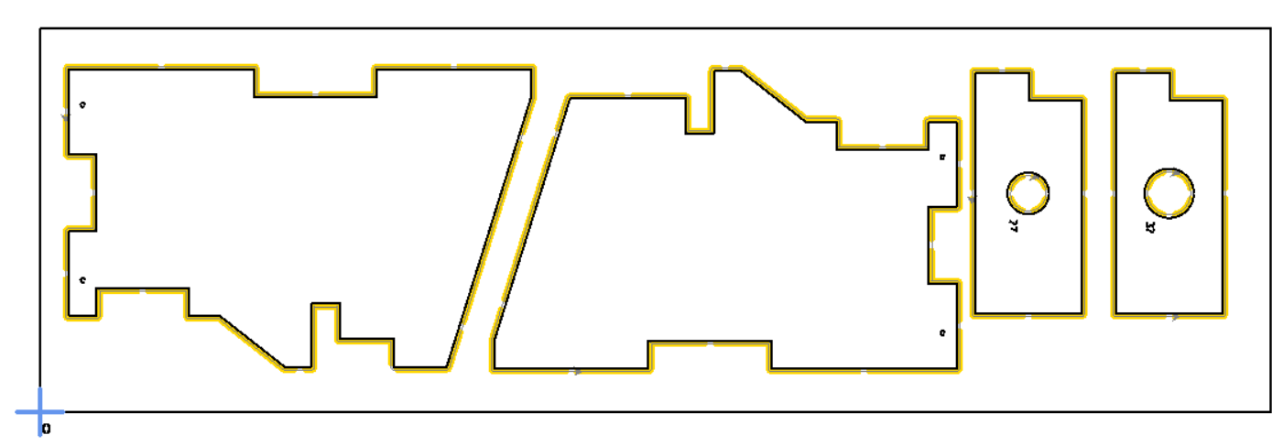
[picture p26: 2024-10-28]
CNC_milling/CNC_milling_Documentation/25cm_overview2.png

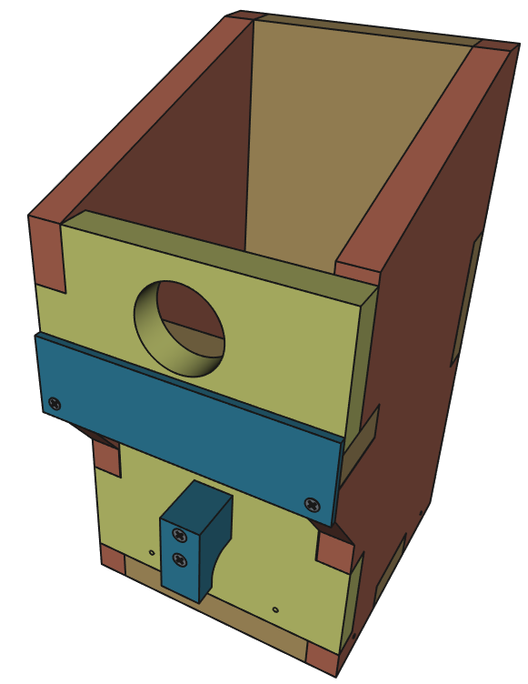
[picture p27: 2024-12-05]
Documentation/tuer_3.png

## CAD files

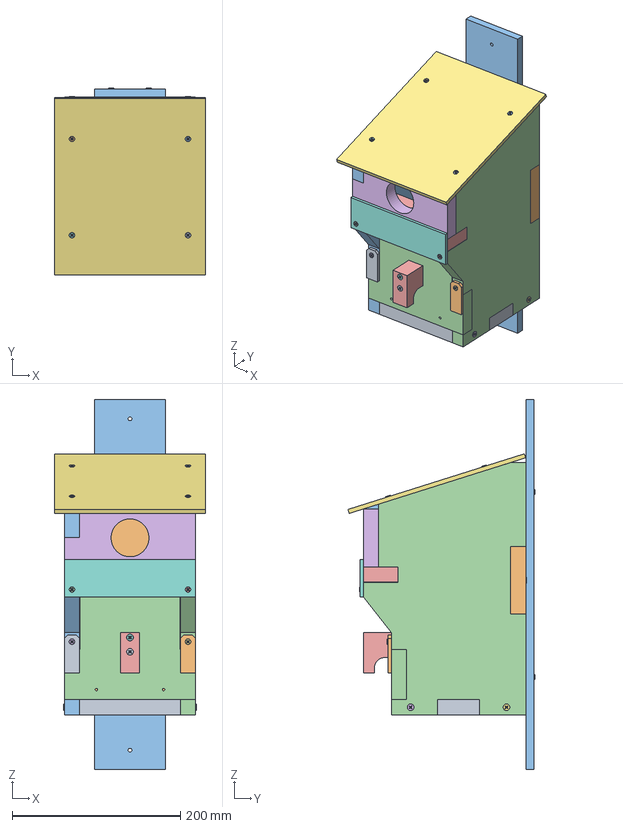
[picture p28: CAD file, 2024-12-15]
CAD/Vogelnistkasten.FCStd
180.0 x 222.5 x 440.0 mm
Boden
Hinten
Links
Rechts (clone)
Prädatorenschutz_Boden
Einfluglochscheibe
Dach
Frontplatte_Plastik
Drehbarer_Halter
Drehbarer_Halter001
Brett_Rückseite_Plastik
Tür_Frontplatte
Griff
#8x1 1/4in-Schraube
#8x1 1/4in-Schraube006
#8x1 1/4in-Schraube007
#8x1 1/4in-Schraube008
#8x1 1/4in-Schraube009
#8x1 1/4in-Schraube010
#6x1in-Schraube
#6x1in-Schraube023
#6x1in-Schraube009
#6x1in-Schraube010
#6x1in-Schraube011
#6x1in-Schraube012
#6x1in-Schraube013
#6x1in-Schraube014
#6x1in-Schraube019
#6x1in-Schraube020
#6x1in-Schraube021
#6x1in-Schraube022
#8x1 1/2in-Schraube
#8x1 1/2in-Schraube001
